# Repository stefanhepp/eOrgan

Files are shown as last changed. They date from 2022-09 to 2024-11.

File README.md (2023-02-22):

README
------

This project contains various parts of a midi-organ. The project consists of four
main parts:

- The Pedalboard: a 29 note midi foot pedal, mostly ARGO compliant. This odd number of notes
  was choosen because of size restrictions (I wanted it to fit under my e-piano).
- The organ console: contains stops, a lcd display, and all connectors and hardware to wire it to a PC.
  Up to three midi keyboards can be used as input devices, as well as the midi pedalboard.
- The organ desk: a framework for all the parts, contains speakers and some additional foot-stops.
  This is also designed to hold the PC. 
- The software: A controller software which allows access to some special features of the hardware
  and sets up the software synthesizer.

License
-------
Shield: [][cc-by-sa]

This work is licensed under a
[Creative Commons Attribution-ShareAlike 4.0 International License][cc-by-sa].

[][cc-by-sa]

[cc-by-sa]: http://creativecommons.org/licenses/by-sa/4.0/
[cc-by-sa-image]: https://licensebuttons.net/l/by-sa/4.0/88x31.png
[cc-by-sa-shield]: https://img.shields.io/badge/License-CC%20BY--SA%204.0-lightgrey.svg

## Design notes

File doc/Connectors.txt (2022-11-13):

Main Connector Groups
======================
o) Pedal
> Midi-Out   (Din5)
<  Power 5V+  (Buchse)

o) 10pin AVR ISP
 1: MOSI
 2: +5V
 3: (NC)
 4: GND
 5: RESET
 6: GND
 7: SCK
 8: GND
 9: MISO
10: GND

o) DIN-5 MIDI
 1: - 
 2: GND
 3: -
 4: 5V
 5: TX

o) 10pin Board Connector
 1: > UART TX
 2: > VCC 5V 
 3: < UART RX
 4: > VCC 12V 
 5: < Interrupt (Open Collector)
 6: > VCC 12V 
 7: > I2C SCL
 8: = GND
 9: = I2C SDA
10: = GND

o) 6pin MiniDIN Board Connector
 1: = I2C SDA
 2: < Interrupt (Open Collector
 3: = GND
 4: > VCC 5V
 5: > I2C SCL
 6: > VCC 12V

Archive
-------

O) Internal Connectors
- 8xPwr Conn.
  > VCC 5V                                    1
  = GND                                       2
  < PWR Main                                  2
  > Beleuchtung Spieltisch VCC+               2
  = Shortcut "Connected"                      1
- 36x Centronics Connector (34pol)
  < Beleuchtung On/off Signal to Relais       1
  > Midi In Pedal                             1
  > IO 3xPedal,8xFußsetzer                    11
  < Midi Out -> PC                            1
  < Volume                                    1
  < Boxen On/off                              1
  < Reverb                                    1
  > Line Kopfhörer                            2
  < PC Pwr                                    2
  < PC Reset                                  2
  > PC PWR LED                                2
  > PC HD LED                                 2
  = 2xUSB PC (Keyboard,Mouse,Setzer,..)       8

o) Stops Connector (34pol)
 1: VCC -> LED
 2: GND <- Taster
 3-34: n: Taster to GND, n+1: LED-

o) Stopboard Connector (14pol)
 1: = GND
 2: = GND
 3: > Bank Select/Register
 4: > Write(high)/Read(low)
 5: > A4
 6: > Read Enabled/LED Data (Write High)
 7: > A3
 8: < Interrupt/Data (Write low, Read High)
 9: > A2
10: > Koppel/Setzer Enable (low active)
11: > A1
12: > VCC 5V
13: > A0
14: > VCC 5V

o) Panel Connector (14Pol)
 1: = GND
 2: < VCC
 3: = GND
 4: < VCC
 5: < Reset
 6: > TxD
 7: > MOSI
 8: < RxD
 9: < MISO
10: ?
11: < SCK
12: ?
13: - ?VCC Lcd
14: -

o) LCD Connector (18pol, EA DIP204-4)
 1: = GND
 2: = D3
 3: = VCC 5V
 4: = D4 (D0)
 5: < Kontrast
 6: = D5 (D1)
 7: < RS/CS Befehl/Daten (Low for Chip Select in Serial Mode)
 8: = D6 (D2)
 9: < RW H=Read, L=Write (Data input in Serial Mode)
10: = D7 (D3), MSB
11: < SCLK Enable (fallende Flanke) (Clock in Serial Mode)
12: -
13: = D0, LSB (Data Out in Serial Mode)
14: < RESET (Low Active, interner Pullup 10K)
15: = D1
16: = A Led Beleuchtung +
17: = D2
18: = C Led Beleuchtung -  

o) LCD Keys Connector (12pol Pinheader)
 1: = GND
 2: = GND
 3: > Kontrast Poti In
 4: < Kontrast Poti Out
 5: < T1
 6: < T2
 7: < T3
 8: < T4
 9: < T5
10: < T6
11: < T7
12: < T8

o) Impuls Connector (Drehimpulsknopf, 5Pol)
 1: < A
 2: < C
 3: < B
 4: < P1
 5: > P2

o) Control Connector (20pol)
 1: > VCC
 2: = GND
 4: < Pwr Main Led
 5: < Pwr Light Led
 6: > Pwr Main
 7: < Pwr Light Sw
 8: < Pwr Main
 9: < Hdd Led
10: > Pwr Sw
11: > Hdd Led
12: < Pwr Sw
13: > Reset Sw
14: < Boxen Sw
15: < Reset Sw
16: < Boxen Led
17: > Pwr Led
18: < Pwr Led
19: < Reverb
20: < Volume

o) Koppel Register

o) Data Connector

-- Onboard Connector --
o) Register (2x)
> 1x Register
< 2x Drawknob

o) Controller
= 2x Register
< 1x Koppel
< 3x Midi-In
> 1x Midi-Out
= 1x Panel
= 1x Control
< 1x Koppel
= 1x Data

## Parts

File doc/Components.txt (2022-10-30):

o) Pedal
1x  AT90S2313P/AtMega48
1x  4069
1x  4556
1x  DIL Socket 20pin
1x  DIL Socket 16pin
1x  DIL Socket 14pin
1x  Quarz 4Mhz
1x  Pin Header male 2x7 pin
1x  Pin Header male 2x5 pin
1x  Pin Header male 2x3 pin
1x  Pin Header female 2x7 pin
2x  220R
10x 4k7
1x  Taster
1x  DIN 180° 5pin female
1x  Pwr out
1x  7805
1x  1N4004
1x  100nF
1x  10uF
32x Reed switch
32x 1N4148

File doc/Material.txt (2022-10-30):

---- Pedal ----
o) Tasten: 29 Keys, Kiefer/Esche, 2.5cm 
  29x	82 x 3x2.5cm hell
  17x	65 x 3x2.5cm hell
  12x	18 x 6x2.5cm dunkel/hell+lack (= 24x 18x3x2.5cm)

o) Rahmen: Kiefer 2cm
  4x	48 x 10x2cm
  2x	85 x 10x2cm
  4x	65 x 12x2cm
  1x	1m x 12x2cm (2xToeboard)
  2x	12 x 12x2cm

o) Struktur: Fichte,Kiefer
  2x	90 x 10x2cm
  2x	10 x 10x2cm
  2x	52 x 12x2cm
  2x	46 x 3x2.5cm
  4x	 8 x 3x2.5cm
  2x	62 x 2x2.5cm
  4x	62 x 0.5x3cm
  2x	46 x 1cm halbrund
  31x	10 x 1cm rund
  29x	2.5 x 0.6cm rund

o) Sonstiges
  4x	12 x 10x0.3cm Blech
  2x	46 x 2cm Filz grün/blau
  58x	10 x 2cm Filz grün/blau
  29x	2 x 2cm Filz grün/blau
  2x	5cm Scharnier
  29x	4x0.2cm Stahlnagel
  29x	7.5 x M8 Feder

------------------
  3x	2m x 10x2cm Kiefer
	 1x 4x48
	 1x 2x82
	 1x 2x90+2x10 + 2x 58x2x2.5
  2x	2m x 12x2cm Kiefer
	 1x 3x65
	 1x 1x65+2x55+2x12
  1x	1m x 12x2cm Kiefer (2x Toeboard)
  6x	2m x 3x2.5cm Esche
	 5x 3x65
	 1x 2x65+1x46
  14x	2m x 3x2.5cm Kiefer
	12x 2x82+2x18
	 2x 2x82+4x8
	 1x 1x46+1x82
  1x	2m x  3x0.5cm Kiefer (3x62)
  1x	1m x  3x0.5cm Kiefer (1x62)
  4x	1m x 1cm rund Buche
  2x	1m x 0.6cm rund Buche
  1x	1m x 1cm halbrund
  1x	50cm x 100x3mm Blech
  1x	40cm x 40cm Filz grün/blau

---- Bank -----
  1x	120 x 30x3cm
  2x	65  x 30x3cm
  3x	110 x 10x3cm

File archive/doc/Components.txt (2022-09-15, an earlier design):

o) Pedal
1x  AT90S2313P/AtMega48
1x  4069
1x  4556
1x  DIL Socket 20pin
1x  DIL Socket 16pin
1x  DIL Socket 14pin
1x  Quarz 4Mhz
1x  Pin Header male 2x7 pin
1x  Pin Header male 2x5 pin
1x  Pin Header male 2x3 pin
1x  Pin Header female 2x7 pin
2x  220R
10x 4k7
1x  Taster
1x  DIN 180° 5pin female
1x  Pwr out
1x  7805
1x  1N4004
1x  100nF
1x  10uF
32x Reed switch
32x 1N4148

o) LcdPanel
1x  AtMega48
1x  DIL Socket 28pin
1x  Quarz 16Mhz
2x  22pF
1x  Pin Header male 2x5 pin
1x  Pin header male 1x5 pin
1x  Pin header male 2x6 pin
1x  Pin header male 2x7 pin
2x  Pin header female 1x10pin, 2mm
1x  Pin header female 1x5 pin
3x  33nF
4x  10k
1x  BC557
1x  680
1x  27
8x  Button
1x  Impulsgeber

o) Register (2x)
4x  4099
2x  4067
1x  4572
1x  4023
1x  4556
2x  DIL Socket 24pin
6x  DIL Socket 16pin
1x  DIL Socket 14pin
2x  Pin header male 2x17 pin
1x  Pin header male 2x7 pin
1x  Pin header male 2x1 pin
2x  Pin header female 2x17 pin
32x 220R
1x  10k
29x Led yellow
2x  Led green
1x  Led red

o) Control Panel 
1x  Keylock
1x  Switch + LED green (pwr)
2x  Taster + LED green/red
2x  Switch
2x  Poti
1x  Pin header female 2x7 pin

o) Koppler
12x Taster + LED (square)
6x  Taster + LED (round)
6x  Wippschalter/Taster 2pos + LED
6x  Wippschalter 3pos
2x  Taster
1x  Poti

o) Audio panel
2x  Klinke 3.5mm
2x  USB Port
2x  Poti (Volume)

o) Controller
3x  AtMega16
3x  DIL socket 40pin
1x  7805
3x  Quarz 16Mhz
5x  DIN 180° 5pin female
4x  6N125
3x  Pin header male 2x7 pin
1x  USB header
2x  Zehner 3.7V
2x  68R
1x  1k5
2x  22pF
1x  100nF
1x  10uF

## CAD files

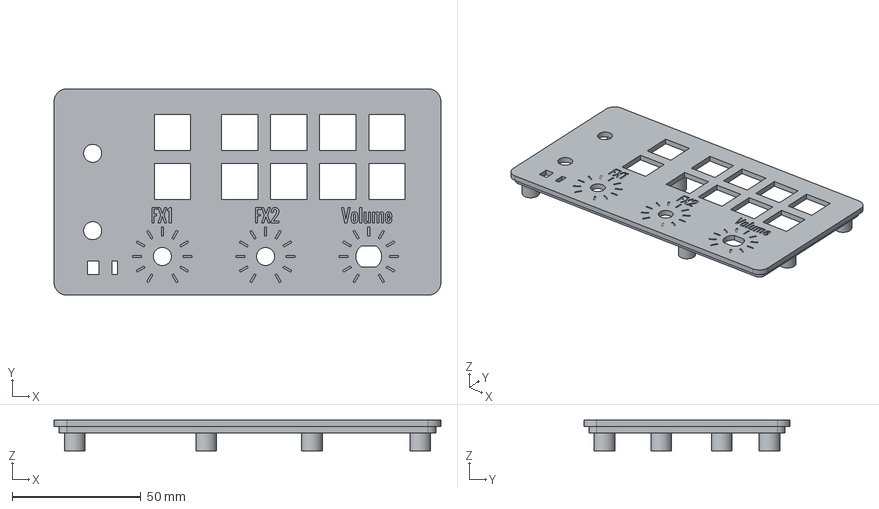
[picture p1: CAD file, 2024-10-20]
design/Panel Inserts-MainControl.step
150.0 x 80.0 x 12.0 mm

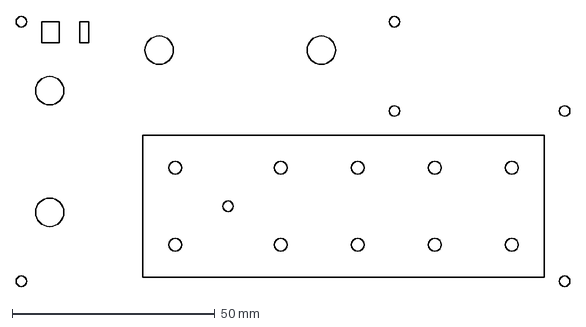
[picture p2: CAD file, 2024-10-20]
design/Panel Inserts-MainControlPCB Drillholes.dxf
136.6 x 66.6 mm

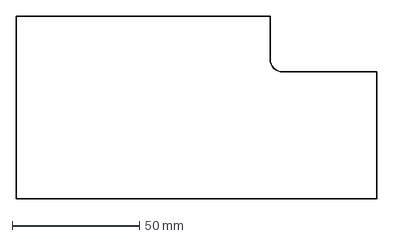
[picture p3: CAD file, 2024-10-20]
design/Panel Inserts-MainControlPCB Edgecut.dxf
142.0 x 72.0 mm

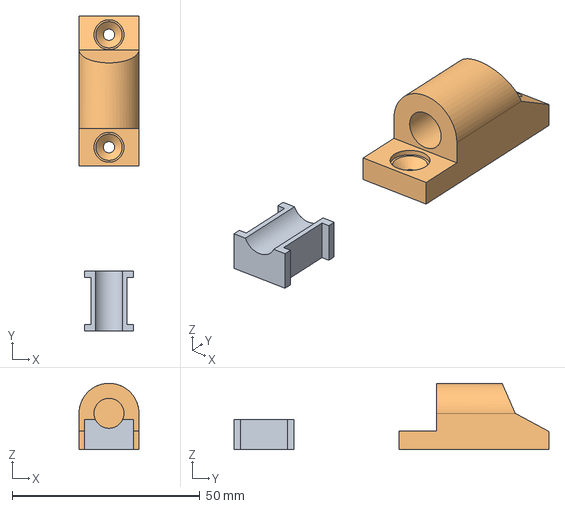
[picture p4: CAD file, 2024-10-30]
design/Musicstand Holder.FCStd
16.0 x 84.0 x 17.7 mm
Spacer
Top

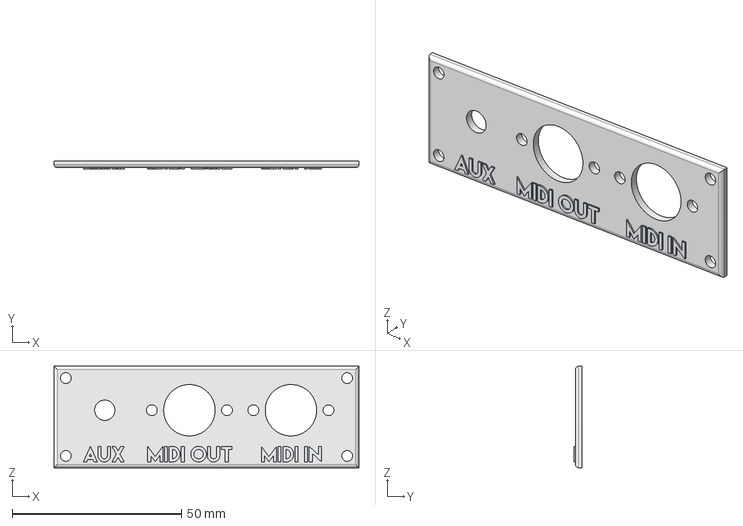
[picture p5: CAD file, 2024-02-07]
design/parts/Audio Frontpanel.FCStd
90.1 x 2.40 x 30.0 mm

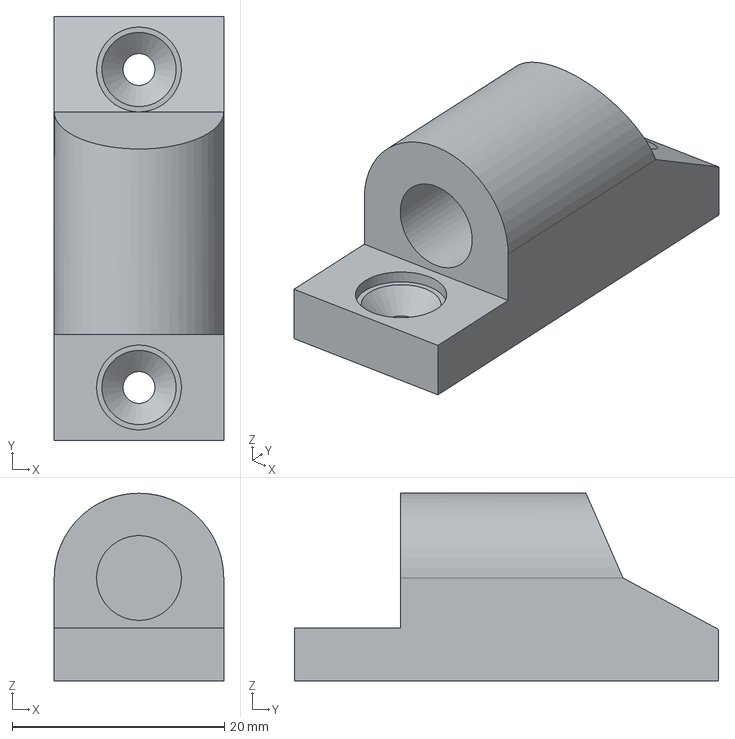
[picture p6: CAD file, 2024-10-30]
design/Musicstand Holder-Top.step
16.0 x 40.0 x 17.7 mm

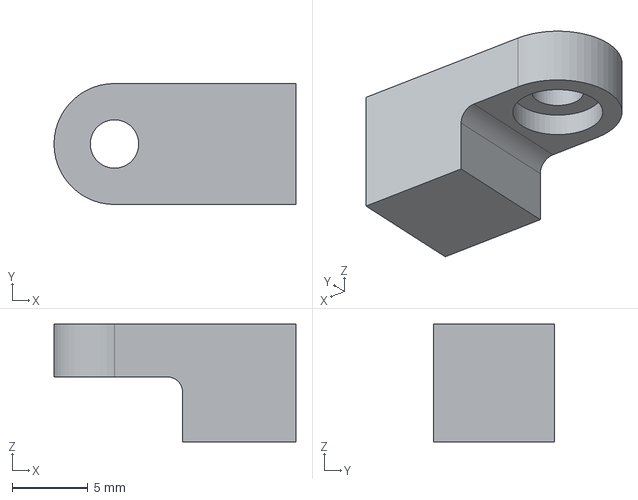
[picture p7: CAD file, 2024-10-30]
design/Display Clamp.step
16.0 x 8.00 x 7.80 mm

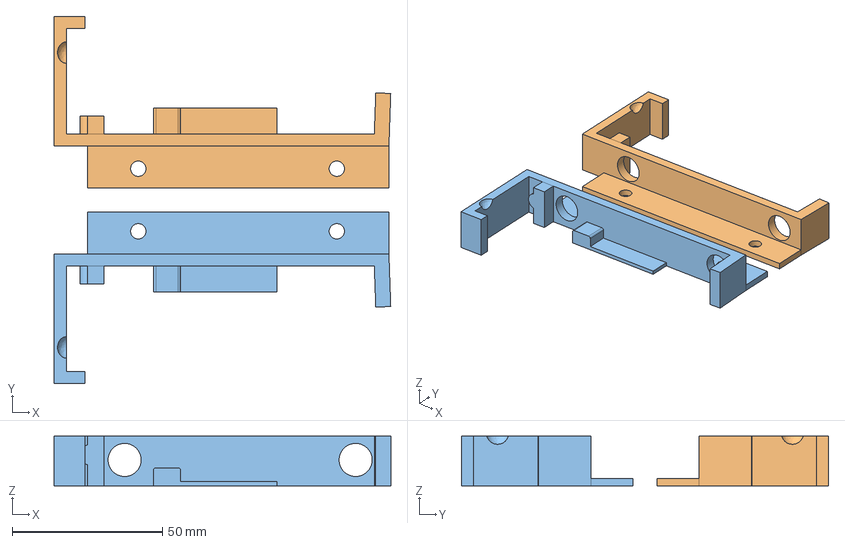
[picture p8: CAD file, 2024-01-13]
design/parts/BoutiqueBracketWRetentionHook.FCStd
111.9 x 122.0 x 16.5 mm
RBracket
CloneBody
LBracket

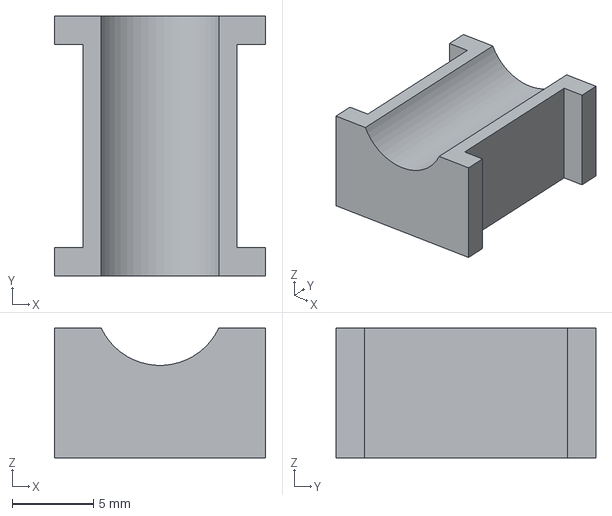
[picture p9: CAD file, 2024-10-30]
design/Musicstand Holder-Spacer.step
13.0 x 16.0 x 8.00 mm

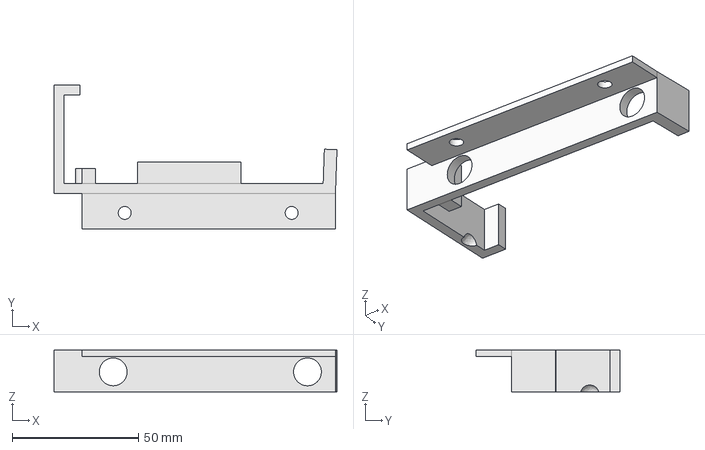
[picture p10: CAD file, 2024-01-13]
design/parts/BoutiqueBracketWRetentionHook-LBracket.step
111.9 x 57.0 x 16.5 mm

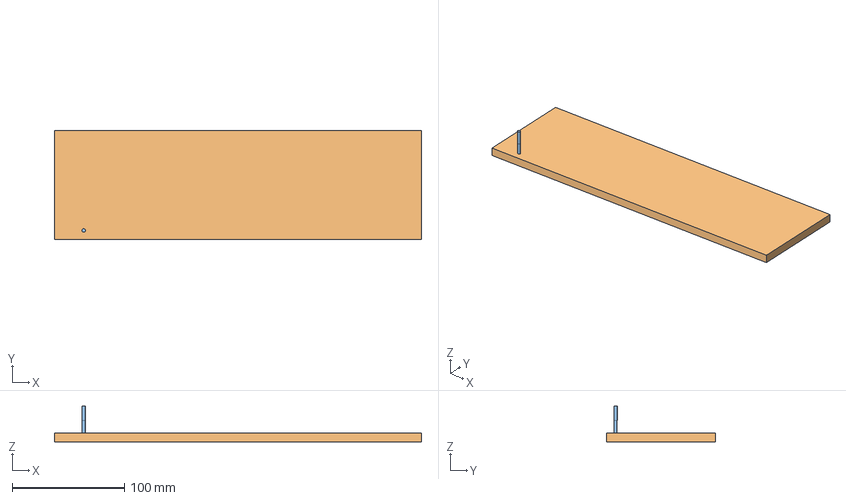
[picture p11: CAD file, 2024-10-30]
design/Panel Cutout Right.FCStd
327.0 x 97.0 x 32.0 mm
Model-Body
Stock
3mm 2-flute Endmill

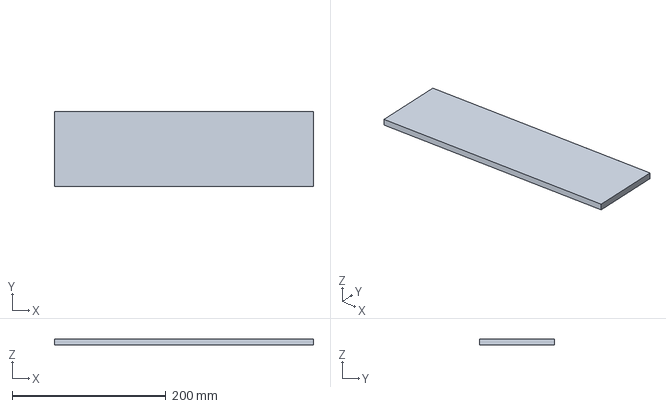
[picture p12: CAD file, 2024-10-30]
design/Panel Cutout Display.FCStd
337.0 x 97.0 x 8.00 mm

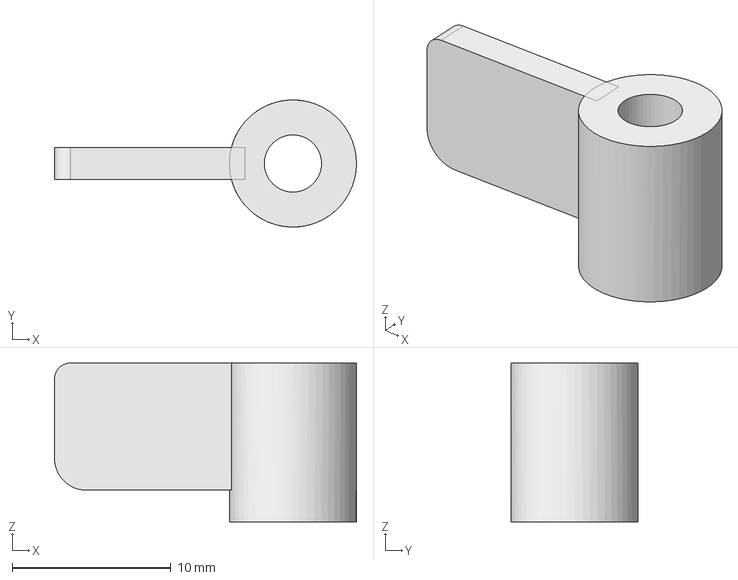
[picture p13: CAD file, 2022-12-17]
design/parts/Hatchlock.FCStd
19.0 x 8.00 x 10.0 mm

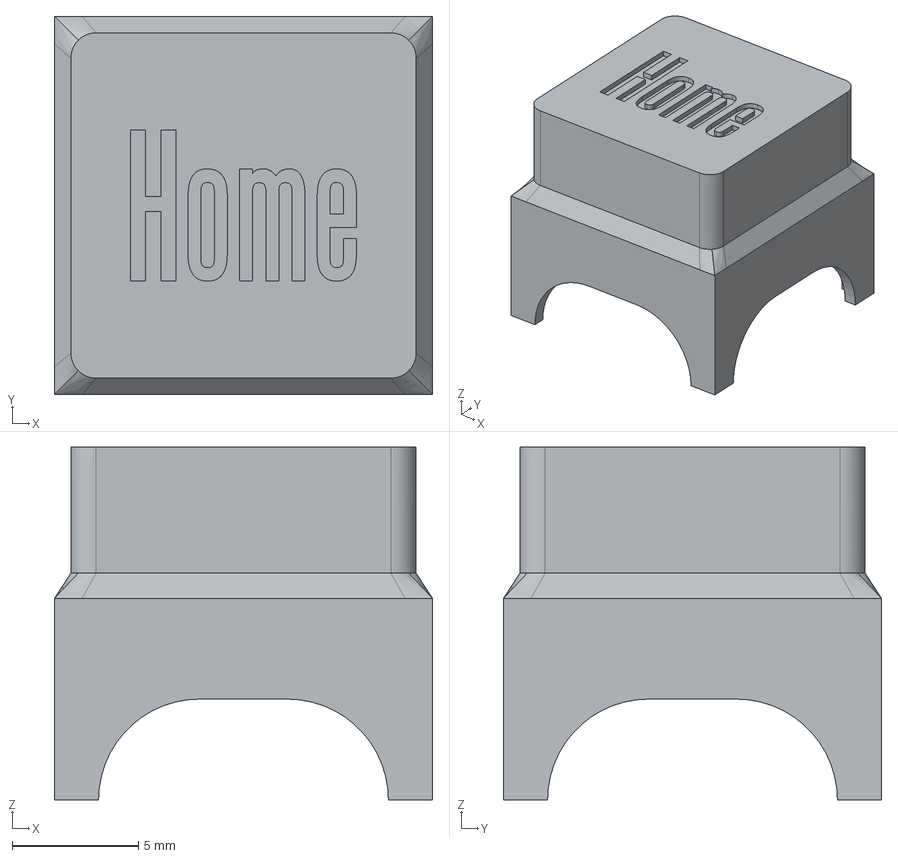
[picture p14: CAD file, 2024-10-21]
design/Panel Keycaps-Keycap Home.step
15.0 x 15.0 x 14.0 mm

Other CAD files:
design/parts/Audio Frontpanel-Panel.step
design/parts/BoutiqueBracketWRetentionHook-RBracket.step
design/parts/Powerswitch Case.FCStd
design/Panel Keycaps-Keycap OK.step
design/Display Clamp.FCStd
design/Lock Mount-Body Left.step
design/Lock Mount-Body Right.step
design/Lock Mount.FCStd
design/Music Rack.FCStd
design/Organ-v2.blend
design/Organ.blend
design/PCB Holder Technics-Holder 110x53.step
design/PCB Holder-150x100.step
design/PCB Holder-Base.step
design/PCB Holder-LCD.step
design/PCB Holder-Pedal.step
design/PCB Holder-Technics.step
design/PCB Holder.FCStd
design/Panel Inserts-Buttons.step
design/Panel Inserts.FCStd
design/Panel Keycaps-Keycap Audio.step
design/Panel Keycaps-Keycap Back.step
design/Panel Keycaps-Keycap Coupler.step
design/Panel Keycaps-Keycap Presets.step
design/Panel Keycaps-Keycap Router.step
design/Panel Keycaps-Keycap Seq.step
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

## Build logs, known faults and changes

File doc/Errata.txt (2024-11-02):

Changes
-------

o) PedalEncoder
- ISP header SCK,MISO,MOSI pins fixed
  - Workaround: rewire jumper wires

o) MIDIController
- Fixed mirrored MIDI breakout board connector
  - Workaround: reverse IDC16 board
- Fixed swapped I2S data signals
  - Workaround: cross-wire I2S data lines

o) ToeStudController
- Fixed PS2 pin order
  - Workaround: cross-wire cables MIDIController-IO Board <> ToeStudEncoder and ToeStudEncoder <> Pedal

o) PanelMain
- Fixed 5V Pwr LED using main 5V instead of MainPanel 5V
  - Workaround: none
- Missing pullups on button columns
  - Workaround: Pullup adapter board

o) Panel-Breakout
- Raspberry PI I2C-0 requires external pullups, added
  - Workaround: Added Panel-Breakup-I2CPullup board to add pullups

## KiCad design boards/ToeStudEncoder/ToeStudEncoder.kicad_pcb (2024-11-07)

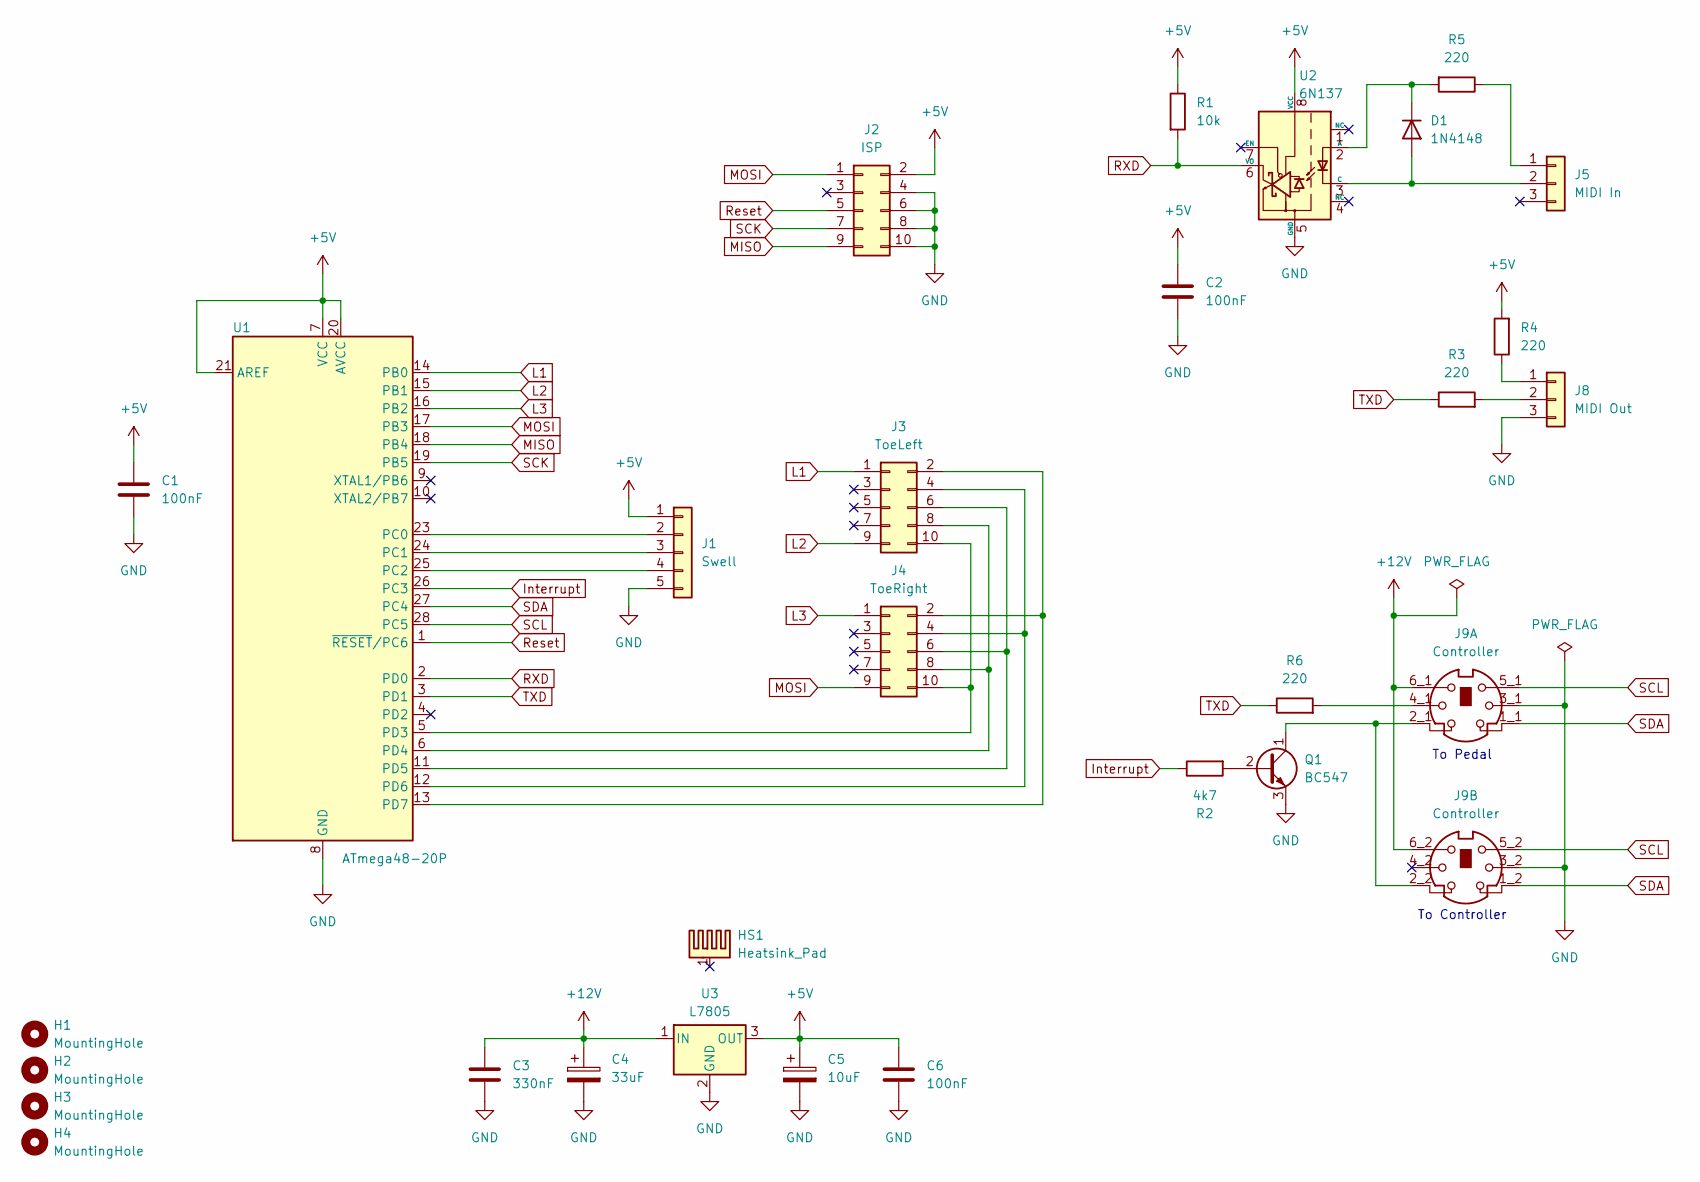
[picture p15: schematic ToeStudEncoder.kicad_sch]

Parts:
C1, C2: 100nF; C_Disc_D7.5mm_W2.5mm_P5.00mm
C3: 330nF; C_Disc_D4.3mm_W1.9mm_P5.00mm
C4: 33uF; CP_Radial_D7.5mm_P2.50mm
C5: 10uF; CP_Radial_D6.3mm_P2.50mm
C6: 100nF; C_Disc_D4.3mm_W1.9mm_P5.00mm
D1: 1N4148; D_DO-35_SOD27_P7.62mm_Horizontal
H1, H2, H3, H4: MountingHole; MountingHole_3mm
HS1: Heatsink_Pad; Heatsink_Aavid_TO-220_H12.7mm
J1: Swell; JST_XH_B5B-XH-A_1x05_P2.50mm_Vertical
J2: ISP; IDC-Header_2x05_P2.54mm_Vertical
J3: ToeLeft; IDC-Header_2x05_P2.54mm_Vertical
J4: ToeRight; IDC-Header_2x05_P2.54mm_Vertical
J5: MIDI In; PinHeader_1x03_P2.54mm_Vertical
J8: MIDI Out; PinHeader_1x03_P2.54mm_Vertical
J9: Controller; SWITCHCRAFT_DMD6FRA111
Q1: BC547; TO-92_Inline_Wide
R1: 10k; R_Axial_DIN0207_L6.3mm_D2.5mm_P2.54mm_Vertical
R2: 4k7; R_Axial_DIN0207_L6.3mm_D2.5mm_P2.54mm_Vertical
R3, R4, R6: 220; R_Axial_DIN0207_L6.3mm_D2.5mm_P10.16mm_Horizontal
R5: 220; R_Axial_DIN0207_L6.3mm_D2.5mm_P2.54mm_Vertical
U1: ATmega48-20P; DIP-28_W7.62mm
U2: 6N137; DIP-8_W7.62mm
U3: L7805; TO-220-3_Vertical

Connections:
+5V: C1.1, C2.1, C5.1, C6.1, J1.1, J2.2, R1.1, R4.2, U1.7 (VCC), U1.20 (AVCC), U1.21 (AREF), U2.8 (VCC), U3.3 (OUT)
+12V: C3.1, C4.1, J9.6_1, J9.6_2, U3.1 (IN)
GND: C1.2, C2.2, C3.2, C4.2, C5.2, C6.2, J1.5, J2.4, J2.6, J2.8, J2.10, J8.3, J9.3_1, J9.3_2, Q1.3 (E), U1.8 (GND), U1.22 (GND), U2.5 (GND), U3.2 (GND)
Interrupt: R2.1, U1.26 (PC3)
L1: J3.1, U1.14 (PB0)
L2: J3.9, U1.15 (PB1)
L3: J4.1, U1.16 (PB2)
MISO: J2.9, U1.18 (PB4)
MOSI: J2.1, J4.9, U1.17 (PB3)
unnamed: D1.2 (A), J5.2, U2.3 (C)
unnamed: D1.1 (K), R5.2, U2.2 (A)
unnamed: J1.2, U1.23 (PC0)
unnamed: J1.3, U1.24 (PC1)
unnamed: J1.4, U1.25 (PC2)
unnamed: J3.2, J4.2, U1.13 (PD7)
unnamed: J3.4, J4.4, U1.12 (PD6)
unnamed: J3.6, J4.6, U1.11 (PD5)
unnamed: J3.8, J4.8, U1.6 (PD4)
unnamed: J3.10, J4.10, U1.5 (PD3)
unnamed: J5.1, R5.1
unnamed: J8.1, R4.1
unnamed: J8.2, R3.2
unnamed: J9.4_1, R6.2
unnamed: Q1.2 (B), R2.2
unnamed: J9.2_1, J9.2_2, Q1.1 (C)
RXD: R1.2, U1.2 (PD0), U2.6 (VO)
Reset: J2.5, U1.1 (~RESET/PC6)
SCK: J2.7, U1.19 (PB5)
SCL: J9.5_1, J9.5_2, U1.28 (PC5)
SDA: J9.1_1, J9.1_2, U1.27 (PC4)
TXD: R3.1, R6.1, U1.3 (PD1)

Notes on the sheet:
To Controller
To Pedal

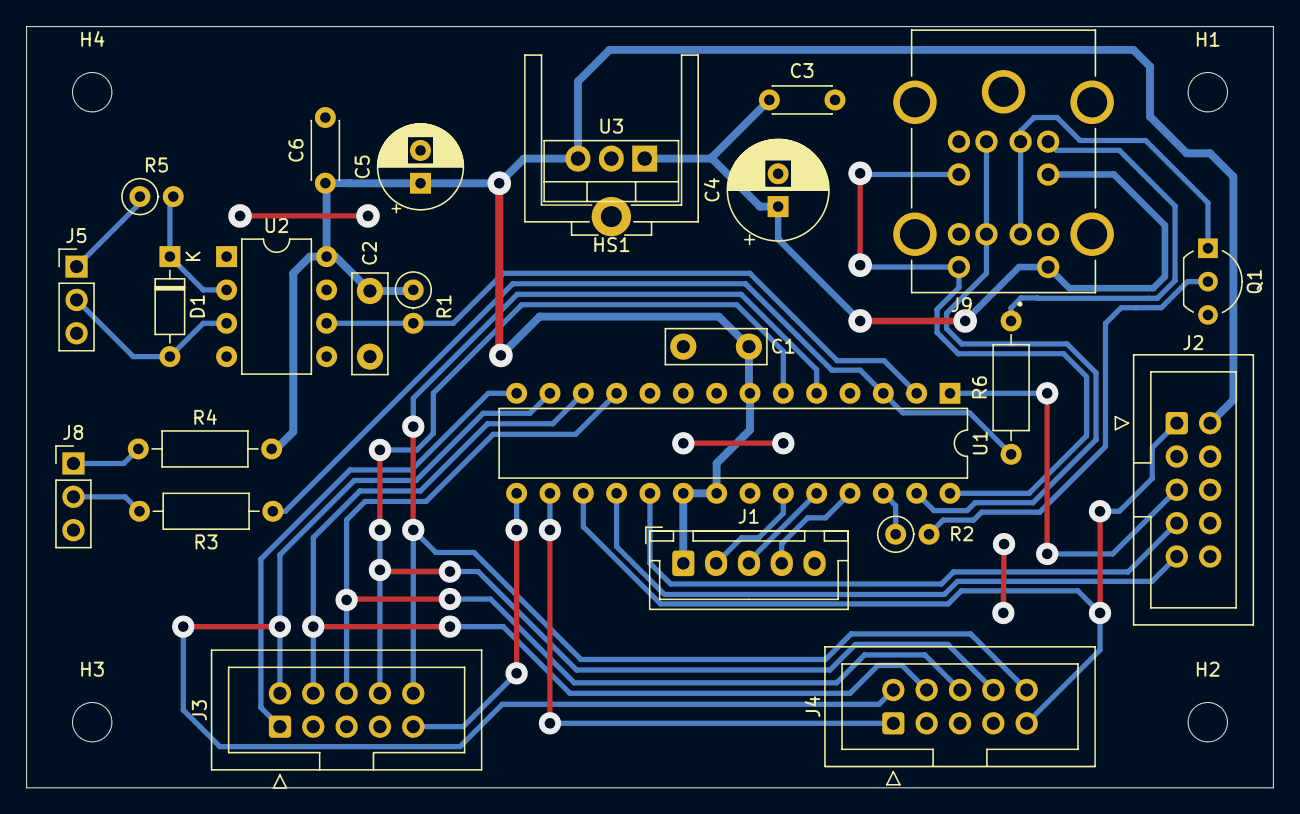
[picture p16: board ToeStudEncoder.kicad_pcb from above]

Board: 2 copper layers, 95.0 x 58.0 mm, 29 parts (0 on the bottom side), 31 nets.

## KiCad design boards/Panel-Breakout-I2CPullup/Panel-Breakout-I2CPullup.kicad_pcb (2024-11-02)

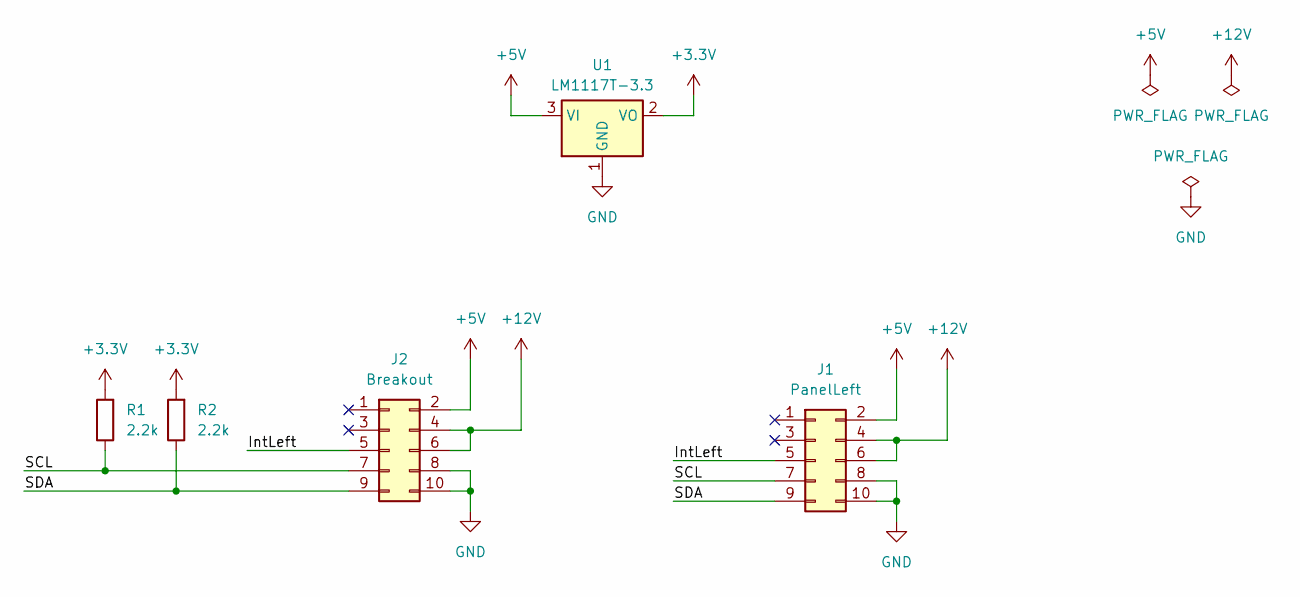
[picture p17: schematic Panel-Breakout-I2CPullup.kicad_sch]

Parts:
J1: PanelLeft; IDC-Header_2x05_P2.54mm_Vertical
J2: Breakout; IDC-Header_2x05_P2.54mm_Vertical
R1, R2: 2.2k; R_Axial_DIN0207_L6.3mm_D2.5mm_P10.16mm_Horizontal
U1: LM1117T-3.3; TO-220-3_Vertical

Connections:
+3.3V: R1.2, R2.2, U1.2 (VO)
+5V: J1.2, J2.2, U1.3 (VI)
+12V: J1.4, J1.6, J2.4, J2.6
/IntLeft: J1.5, J2.5
/SCL: J1.7, J2.7, R1.1
/SDA: J1.9, J2.9, R2.1
GND: J1.8, J1.10, J2.8, J2.10, U1.1 (GND)

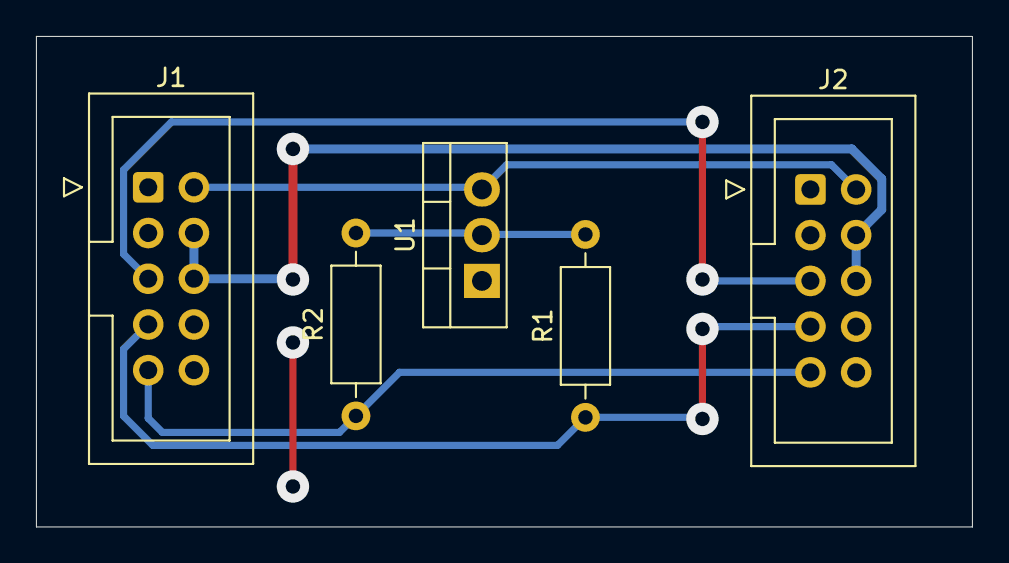
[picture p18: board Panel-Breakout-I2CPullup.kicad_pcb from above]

Board: 2 copper layers, 52.0 x 27.2 mm, 5 parts (0 on the bottom side), 7 nets.

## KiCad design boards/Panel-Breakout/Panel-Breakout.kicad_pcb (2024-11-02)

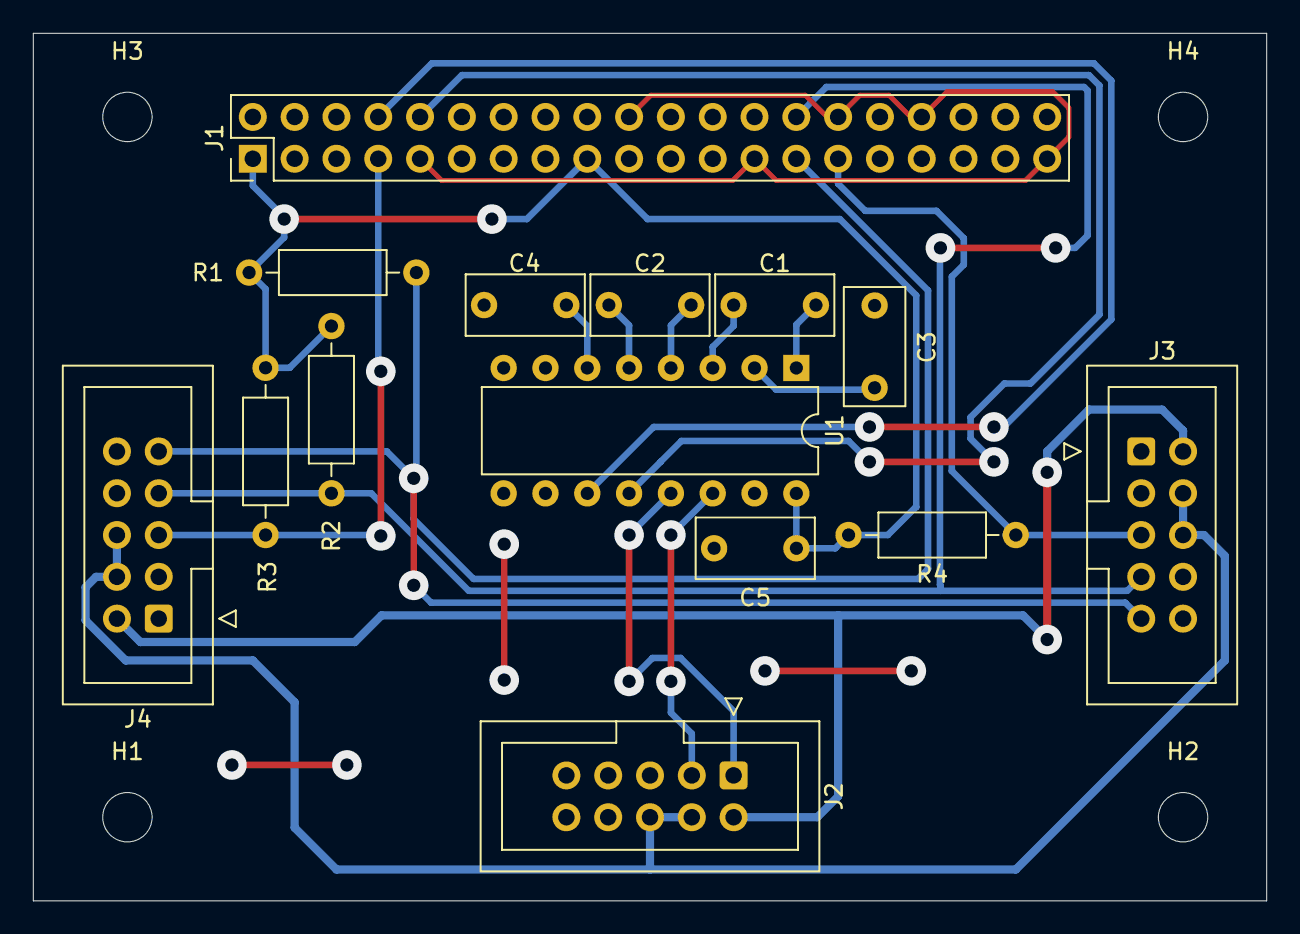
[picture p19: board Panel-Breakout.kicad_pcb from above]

Board: 2 copper layers, 74.9 x 52.7 mm, 18 parts (0 on the bottom side), 18 nets.

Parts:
C1, C2, C3, C4, C5: 0.47uF; C_Rect_L7.0mm_W3.5mm_P5.00mm
H1, H2, H3, H4: MountingHole; MountingHole_3mm
J1: Raspberry_Pi_2_3; PinHeader_2x20_P2.54mm_Vertical
J2: BoardCon; IDC-Header_2x05_P2.54mm_Vertical
J3: PanelLeft; IDC-Header_2x05_P2.54mm_Vertical
J4: PanelRight; IDC-Header_2x05_P2.54mm_Vertical
R1, R2: 2.2k; R_Axial_DIN0207_L6.3mm_D2.5mm_P10.16mm_Horizontal
R3, R4: 10k; R_Axial_DIN0207_L6.3mm_D2.5mm_P10.16mm_Horizontal
U1: ICL3232; DIP-16_W7.62mm

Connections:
+3.3V: C5.1, J1.1 (3V3), J1.17 (3V3), R1.2, R2.2, R3.2, R4.2, U1.16 (VCC)
+5V: J2.2, J3.2, J4.2
+12V: J2.4, J2.6, J3.4, J3.6, J4.4, J4.6
/IntLeft: J1.29 (GCLK1/GPIO5), J3.5, R4.1
/IntRight: J1.7 (GCLK0/GPIO4), J4.5, R3.1
/RPI_RXD: J1.10 (GPIO15/RXD), U1.12 (R1OUT)
/RPI_TXD: J1.8 (GPIO14/TXD), U1.11 (T1IN)
/RS232_RXD: J2.1, U1.13 (R1IN)
/RS232_TXD: J2.3, U1.14 (T1OUT)
/SCL: J1.28 (ID_SC/GPIO1), J3.7, J4.7, R2.1
/SDA: J1.27 (ID_SD/GPIO0), J3.9, J4.9, R1.1
GND: C3.2, C4.2, C5.2, J1.6 (GND), J1.9 (GND), J1.14 (GND), J1.20 (GND), J1.25 (GND), J1.30 (GND), J1.34 (GND), J1.39 (GND), J2.8, J2.10, J3.8, J3.10, J4.8, J4.10, U1.8 (R2IN), U1.10 (T2IN), U1.15 (GND)
unnamed: C1.1, U1.1 (C1+)
unnamed: C1.2, U1.3 (C1-)
unnamed: C2.1, U1.4 (C2+)
unnamed: C2.2, U1.5 (C2-)
unnamed: C3.1, U1.2 (VS+)
unnamed: C4.1, U1.6 (VS-)

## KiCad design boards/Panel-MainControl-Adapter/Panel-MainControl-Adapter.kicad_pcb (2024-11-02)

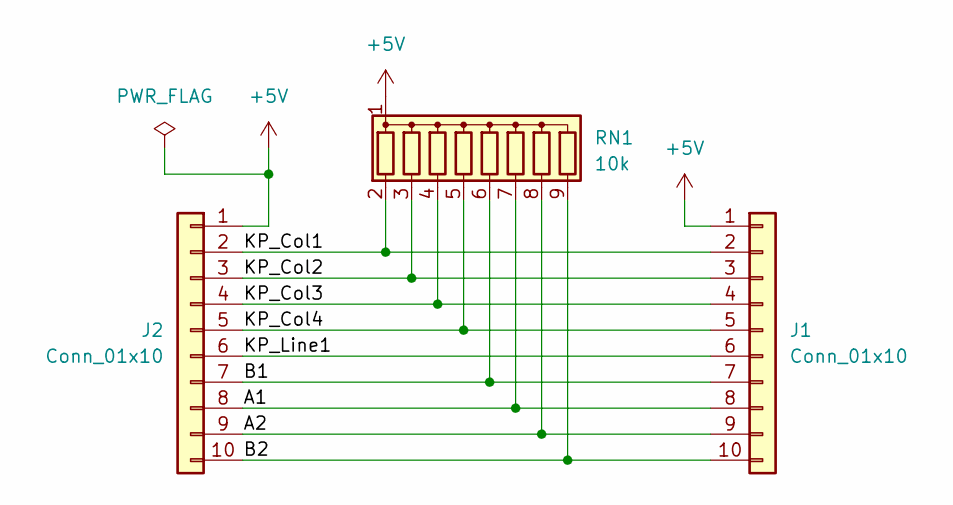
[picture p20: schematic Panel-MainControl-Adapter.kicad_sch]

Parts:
J1, J2: Conn_01x10; PinHeader_1x10_P2.00mm_Vertical
RN1: 10k; R_Array_SIP9

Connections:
+5V: J1.1, J2.1, RN1.1 (common)
/A1: J1.8, J2.8, RN1.7 (R6)
/A2: J1.9, J2.9, RN1.8 (R7)
/B1: J1.7, J2.7, RN1.6 (R5)
/B2: J1.10, J2.10, RN1.9 (R8)
/KP_Col1: J1.2, J2.2, RN1.2 (R1)
/KP_Col2: J1.3, J2.3, RN1.3 (R2)
/KP_Col3: J1.4, J2.4, RN1.4 (R3)
/KP_Col4: J1.5, J2.5, RN1.5 (R4)
/KP_Line1: J1.6, J2.6

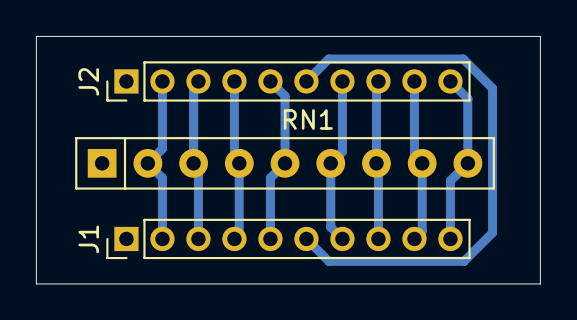
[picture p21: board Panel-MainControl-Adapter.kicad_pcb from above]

Board: 2 copper layers, 28.0 x 13.8 mm, 3 parts (0 on the bottom side), 10 nets.

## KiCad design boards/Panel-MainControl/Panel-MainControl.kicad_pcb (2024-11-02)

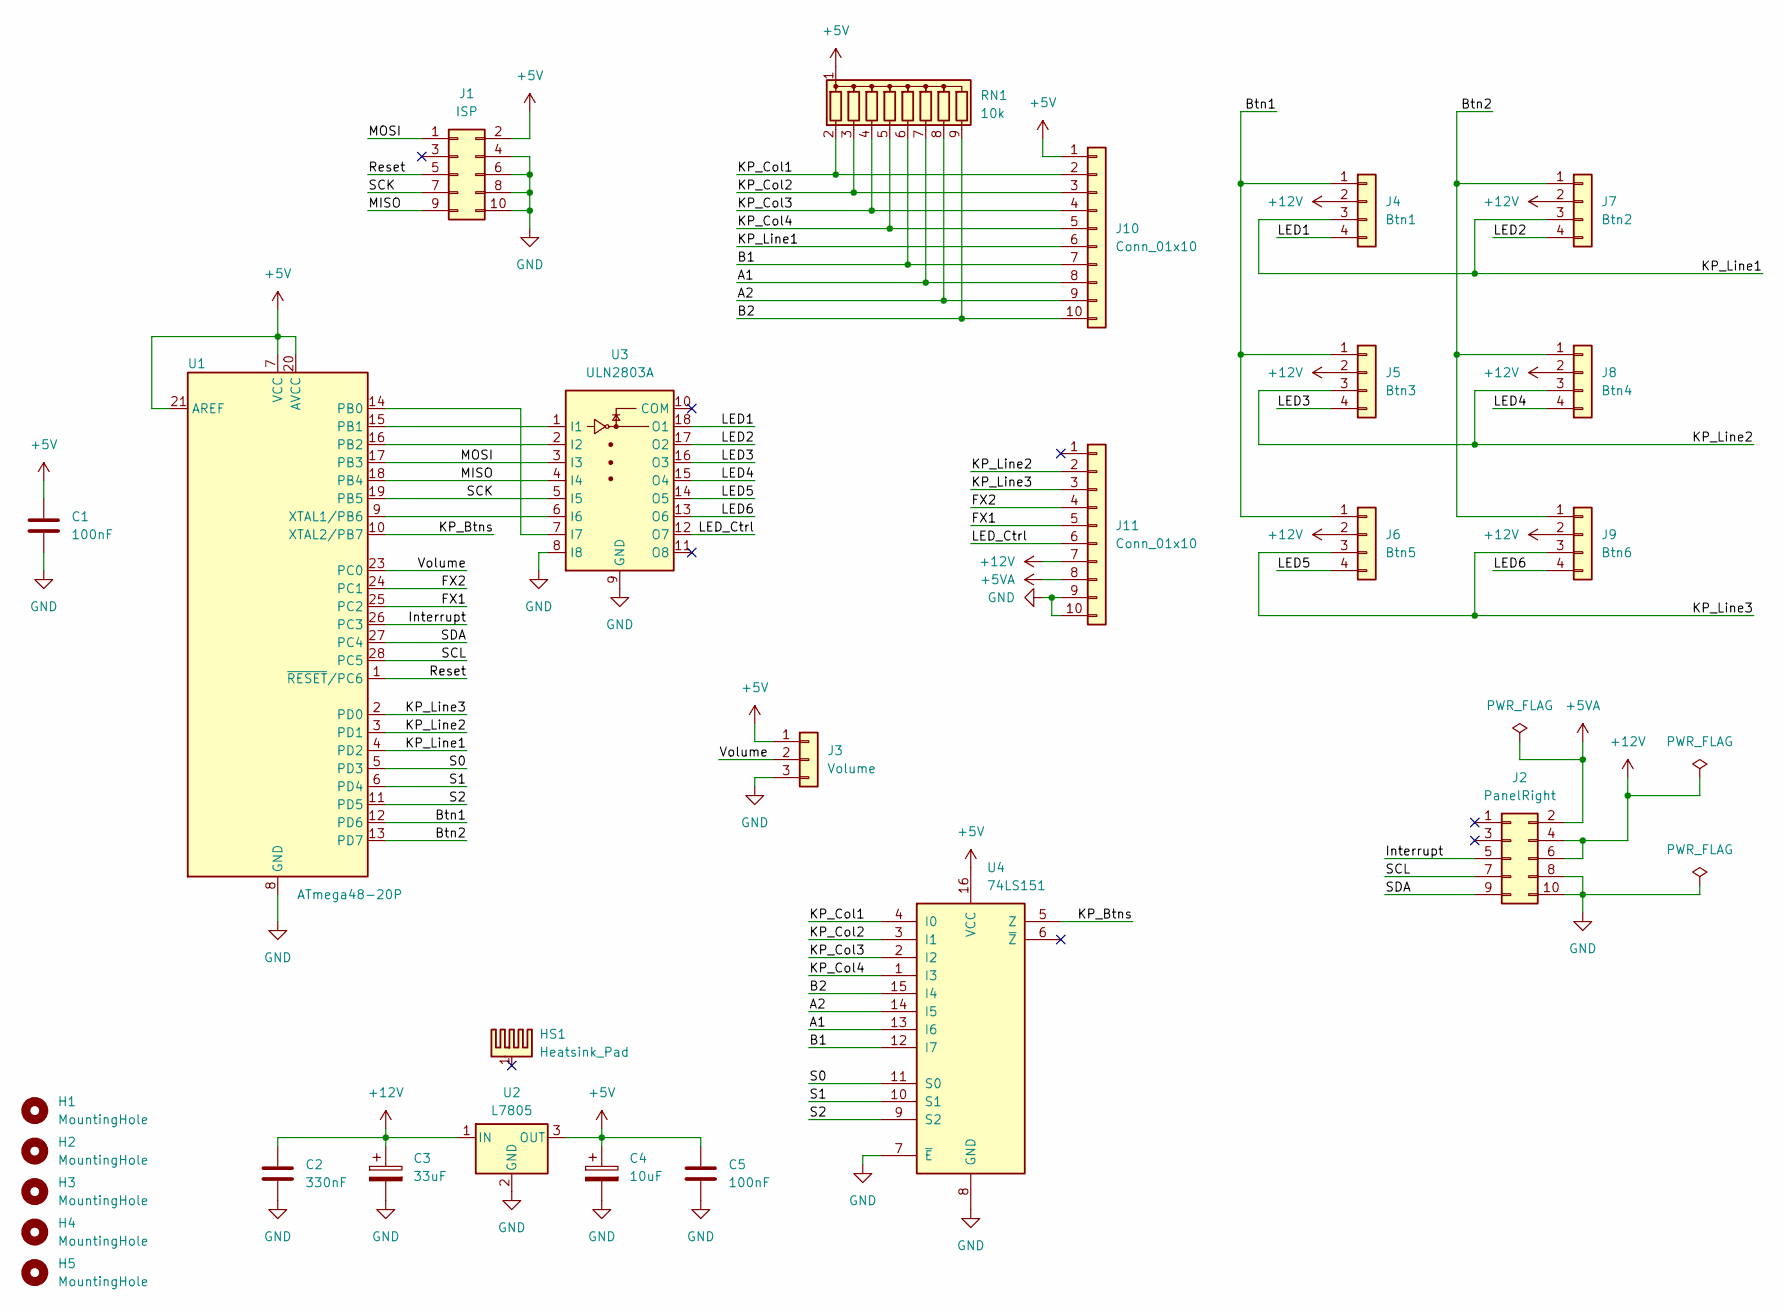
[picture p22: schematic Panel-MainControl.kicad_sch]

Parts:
C1, C5: 100nF; C_Disc_D4.3mm_W1.9mm_P5.00mm
C2: 330nF; C_Disc_D4.3mm_W1.9mm_P5.00mm
C3: 33uF; CP_Radial_D7.5mm_P2.50mm
C4: 10uF; CP_Radial_D6.3mm_P2.50mm
H1, H2, H3, H4, H5: MountingHole; MountingHole_2.7mm_M2.5
HS1: Heatsink_Pad; Heatsink_Aavid_TO-220_H12.7mm
J1: ISP; IDC-Header_2x05_P2.54mm_Vertical
J2: PanelRight; IDC-Header_2x05_P2.54mm_Vertical
J3: Volume; PinHeader_1x03_P2.54mm_Vertical
J4: Btn1; JST_XH_B4B-XH-A_1x04_P2.50mm_Vertical
J5: Btn3; JST_XH_B4B-XH-A_1x04_P2.50mm_Vertical
J6: Btn5; JST_XH_B4B-XH-A_1x04_P2.50mm_Vertical
J7: Btn2; JST_XH_B4B-XH-A_1x04_P2.50mm_Vertical
J8: Btn4; JST_XH_B4B-XH-A_1x04_P2.50mm_Vertical
J9: Btn6; JST_XH_B4B-XH-A_1x04_P2.50mm_Vertical
J10, J11: Conn_01x10; PinHeader_1x10_P2.00mm_Vertical
RN1: 10k; R_Array_SIP9
U1: ATmega48-20P; DIP-28_W7.62mm_Socket
U2: L7805; TO-220-3_Vertical
U3: ULN2803A; DIP-18_W7.62mm
U4: 74LS151; DIP-16_W7.62mm

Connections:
+5V: C1.1, C4.1, C5.1, J1.2, J3.1, J10.1, RN1.1 (common), U1.7 (VCC), U1.20 (AVCC), U1.21 (AREF), U2.3 (OUT), U4.16 (VCC)
+5VA: J2.2, J11.8
+12V: C2.1, C3.1, J2.4, J2.6, J4.2, J5.2, J6.2, J7.2, J8.2, J9.2, J11.7, U2.1 (IN)
/A1: J10.8, RN1.7 (R6), U4.13 (I6)
/A2: J10.9, RN1.8 (R7), U4.14 (I5)
/B1: J10.7, RN1.6 (R5), U4.12 (I7)
/B2: J10.10, RN1.9 (R8), U4.15 (I4)
/Btn1: J4.1, J5.1, J6.1, U1.12 (PD6)
/Btn2: J7.1, J8.1, J9.1, U1.13 (PD7)
/FX1: J11.5, U1.25 (PC2)
/FX2: J11.4, U1.24 (PC1)
/Interrupt: J2.5, U1.26 (PC3)
/KP_Btns: U1.10 (XTAL2/PB7), U4.5 (Z)
/KP_Col1: J10.2, RN1.2 (R1), U4.4 (I0)
/KP_Col2: J10.3, RN1.3 (R2), U4.3 (I1)
/KP_Col3: J10.4, RN1.4 (R3), U4.2 (I2)
/KP_Col4: J10.5, RN1.5 (R4), U4.1 (I3)
/KP_Line1: J4.3, J7.3, J10.6, U1.4 (PD2)
/KP_Line2: J5.3, J8.3, J11.2, U1.3 (PD1)
/KP_Line3: J6.3, J9.3, J11.3, U1.2 (PD0)
/LED1: J4.4, U3.18 (O1)
/LED2: J7.4, U3.17 (O2)
/LED3: J5.4, U3.16 (O3)
/LED4: J8.4, U3.15 (O4)
/LED5: J6.4, U3.14 (O5)
/LED6: J9.4, U3.13 (O6)
/LED_Ctrl: J11.6, U3.12 (O7)
/MISO: J1.9, U1.18 (PB4), U3.4 (I4)
/MOSI: J1.1, U1.17 (PB3), U3.3 (I3)
/Reset: J1.5, U1.1 (~RESET/PC6)
/S0: U1.5 (PD3), U4.11 (S0)
/S1: U1.6 (PD4), U4.10 (S1)
/S2: U1.11 (PD5), U4.9 (S2)
/SCK: J1.7, U1.19 (PB5), U3.5 (I5)
/SCL: J2.7, U1.28 (PC5)
/SDA: J2.9, U1.27 (PC4)
/Volume: J3.2, U1.23 (PC0)
GND: C1.2, C2.2, C3.2, C4.2, C5.2, J1.4, J1.6, J1.8, J1.10, J2.8, J2.10, J3.3, J11.9, J11.10, U1.8 (GND), U1.22 (GND), U2.2 (GND), U3.8 (I8), U3.9 (GND), U4.7 (~E), U4.8 (GND)
unnamed: U1.14 (PB0), U3.7 (I7)
unnamed: U1.15 (PB1), U3.1 (I1)
unnamed: U1.16 (PB2), U3.2 (I2)
unnamed: U1.9 (XTAL1/PB6), U3.6 (I6)

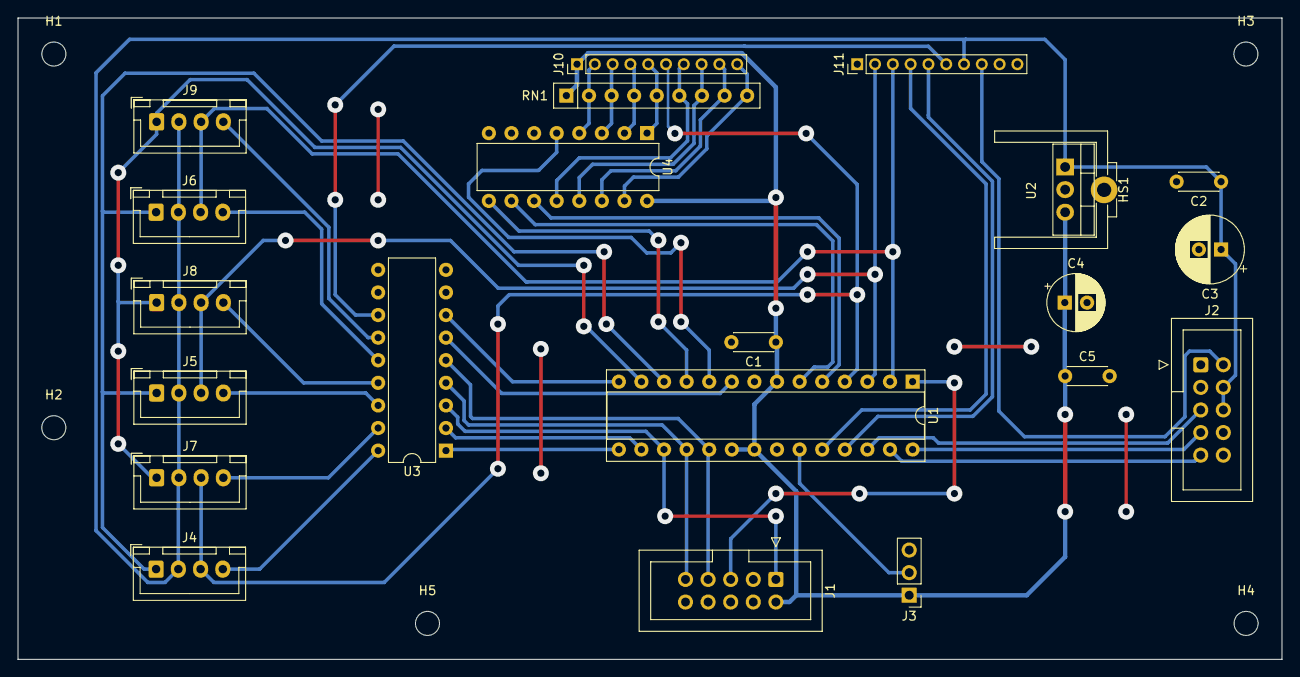
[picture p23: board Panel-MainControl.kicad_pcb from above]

Board: 2 copper layers, 142.1 x 72.1 mm, 27 parts (0 on the bottom side), 42 nets.

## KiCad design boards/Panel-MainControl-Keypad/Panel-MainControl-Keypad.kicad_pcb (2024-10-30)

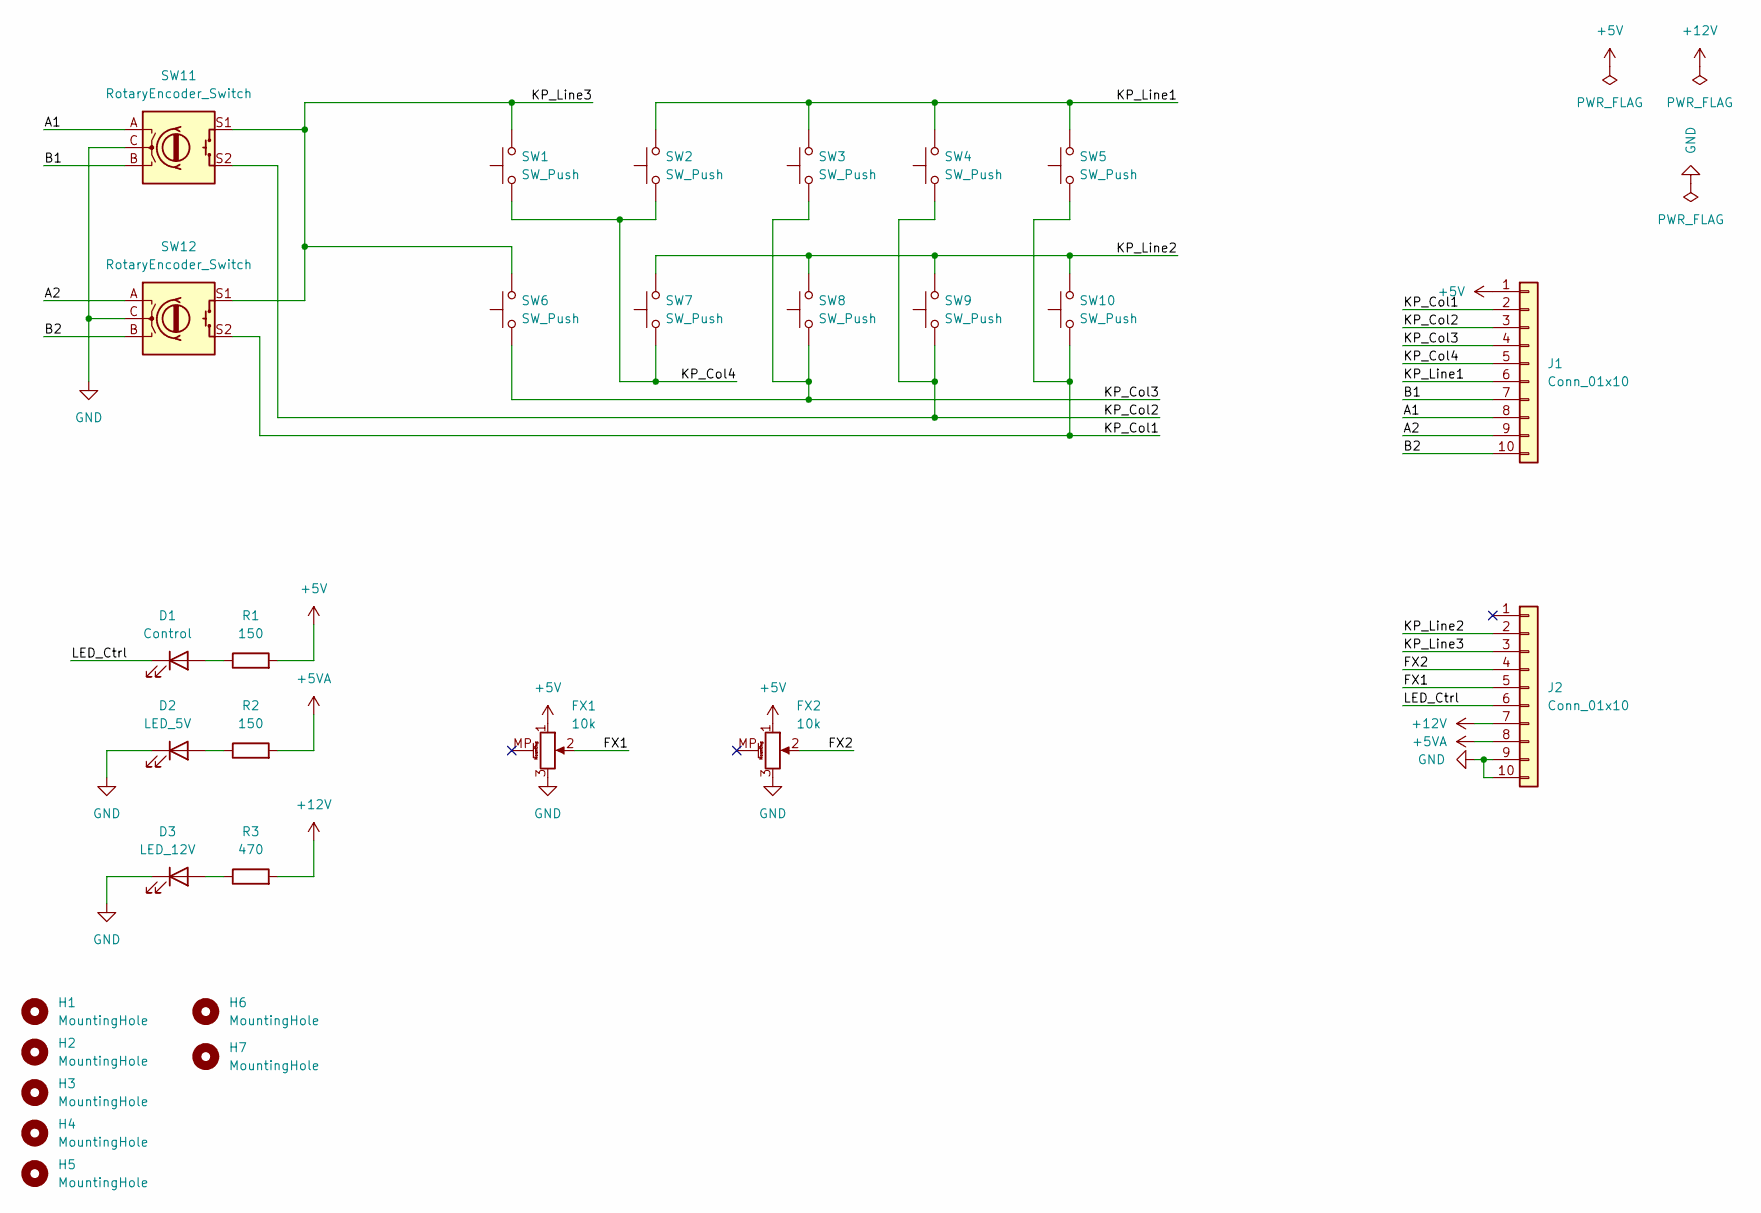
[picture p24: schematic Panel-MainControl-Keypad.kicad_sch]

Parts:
D1: Control; LED_Rectangular_W5.0mm_H2.0mm
D2: LED_5V; LED_Rectangular_W5.0mm_H2.0mm
D3: LED_12V; LED_Rectangular_W5.0mm_H2.0mm
FX1, FX2: 10k; Potentiometer_Alps_RK09K_Single_Vertical
H1, H2, H3, H4, H5, H6, H7: MountingHole; MountingHole_2.7mm_M2.5
J1, J2: Conn_01x10; PinHeader_1x10_P2.00mm_Vertical
R1, R2: 150; R_Axial_DIN0207_L6.3mm_D2.5mm_P10.16mm_Horizontal
R3: 470; R_Axial_DIN0207_L6.3mm_D2.5mm_P10.16mm_Horizontal
SW1, SW2, SW3, SW4, SW5, SW6, SW7, SW8, SW9, SW10: SW_Push; SW_PUSH_6mm_H9.5mm
SW11, SW12: RotaryEncoder_Switch; RotaryEncoder_Switch-PEC11R-4215F

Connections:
+5V: FX1.1, FX2.1, J1.1, R1.2
+5VA: J2.8, R2.2
+12V: J2.7, R3.2
/A1: J1.8, SW11.A
/A2: J1.9, SW12.A
/B1: J1.7, SW11.B
/B2: J1.10, SW12.B
/FX1: FX1.2, J2.5
/FX2: FX2.2, J2.4
/KP_Col1: J1.2, SW5.1, SW10.1, SW12.S2
/KP_Col2: J1.3, SW4.1, SW9.1, SW11.S2
/KP_Col3: J1.4, SW3.1, SW6.1, SW8.1
/KP_Col4: J1.5, SW1.1, SW2.1, SW7.1
/KP_Line1: J1.6, SW2.2, SW3.2, SW4.2, SW5.2
/KP_Line2: J2.2, SW7.2, SW8.2, SW9.2, SW10.2
/KP_Line3: J2.3, SW1.2, SW6.2, SW11.S1, SW12.S1
/LED_Ctrl: D1.1 (K), J2.6
GND: D2.1 (K), D3.1 (K), FX1.3, FX2.3, J2.9, J2.10, SW11.C, SW12.C
unnamed: D1.2 (A), R1.1
unnamed: D2.2 (A), R2.1
unnamed: D3.2 (A), R3.1

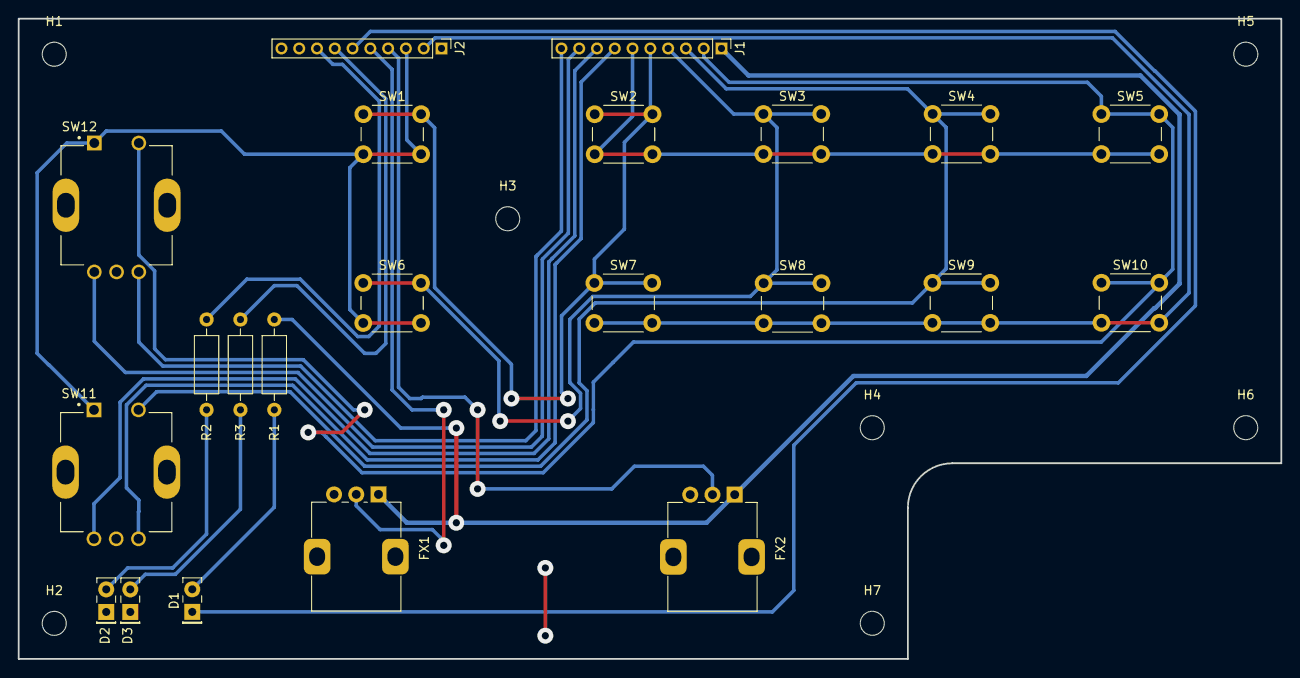
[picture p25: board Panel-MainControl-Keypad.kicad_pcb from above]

Board: 2 copper layers, 142.0 x 72.0 mm, 29 parts (0 on the bottom side), 21 nets.

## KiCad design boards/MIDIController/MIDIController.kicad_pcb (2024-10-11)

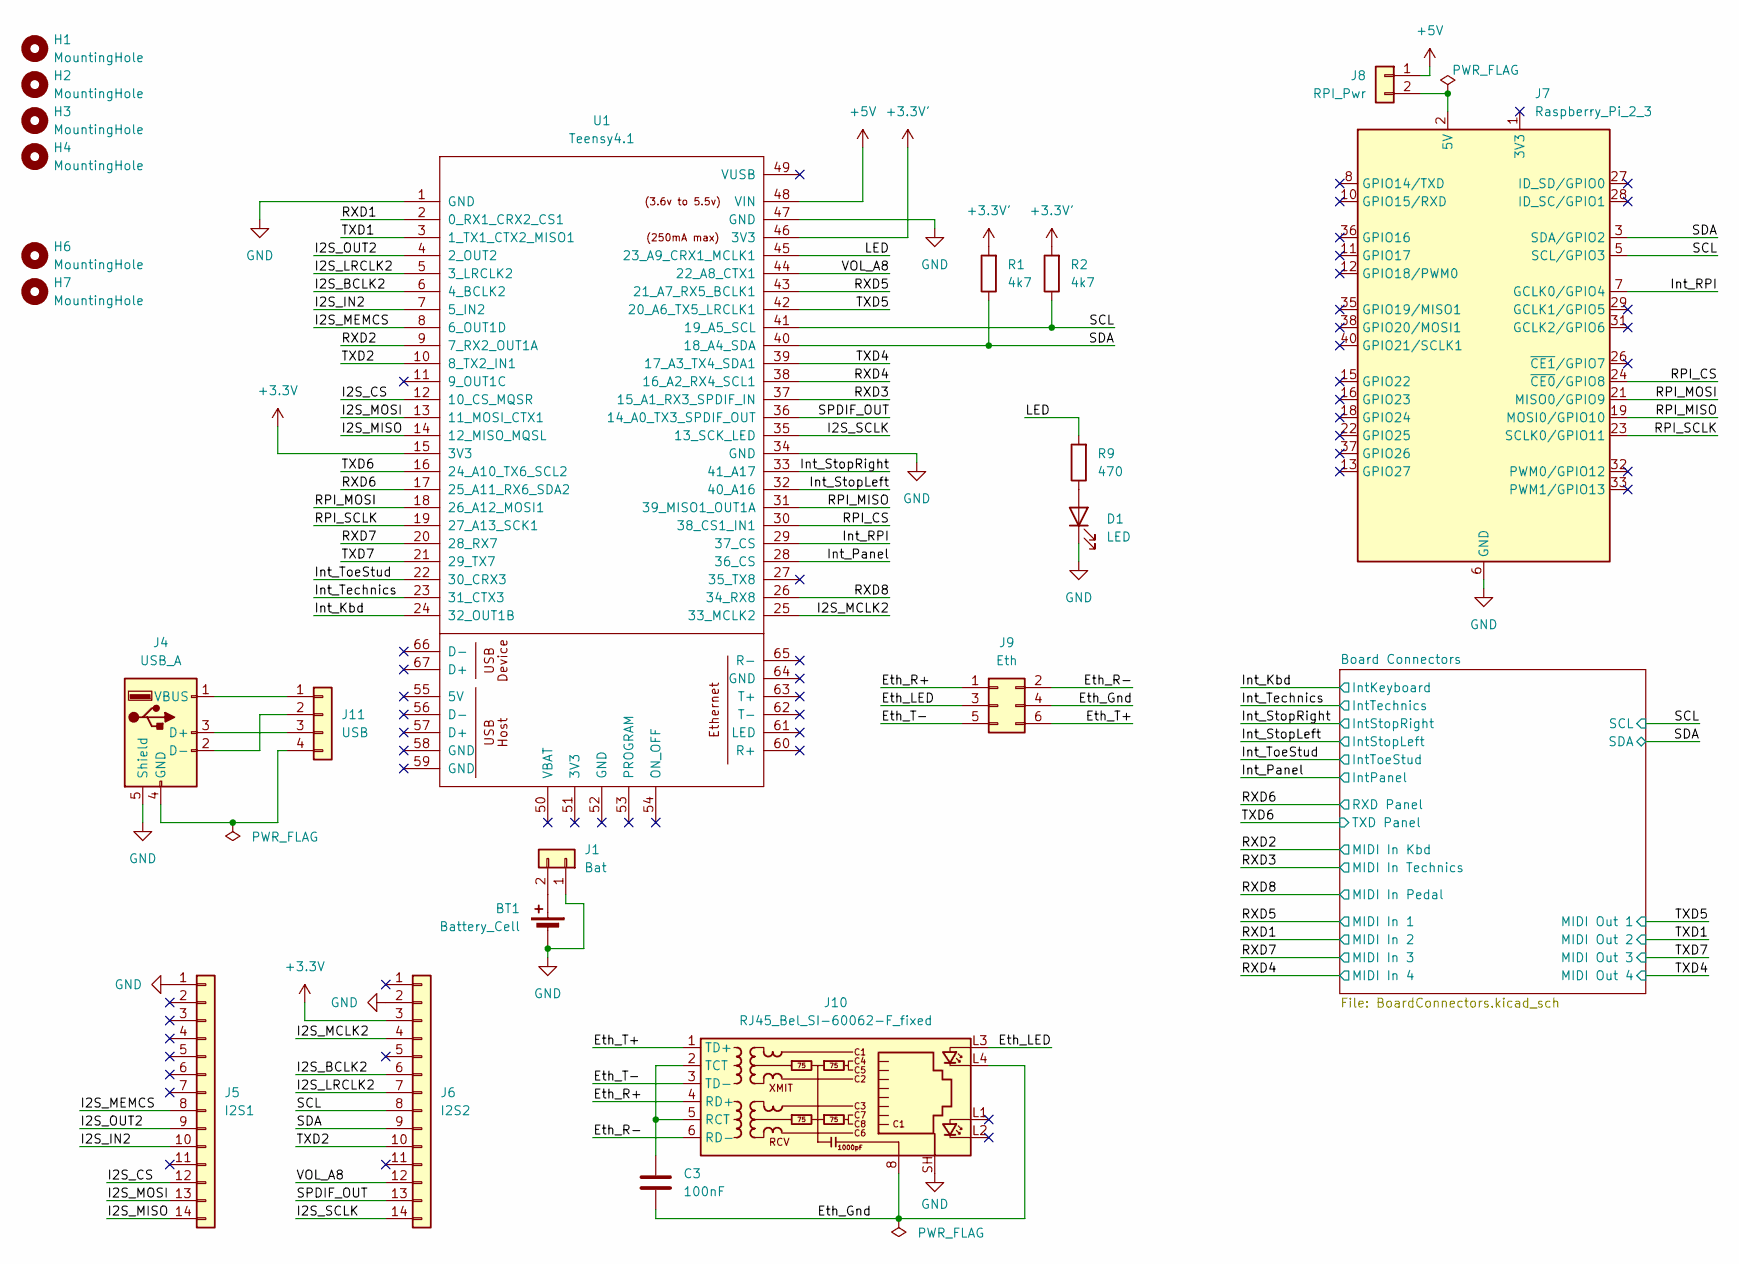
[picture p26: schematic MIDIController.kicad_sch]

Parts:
BT1: Battery_Cell; BatteryHolder_Holder_CR2032
C3: 100nF; C_Disc_D4.3mm_W1.9mm_P5.00mm
D1: LED; LED_D3.0mm
H1, H2, H3, H4: MountingHole; MountingHole_3.2mm_M3
H6, H7: MountingHole; MountingHole_2.7mm_M2.5
J1: Bat; PinHeader_1x02_P2.54mm_Vertical
J4: USB_A; USB_A_Molex_67643_Horizontal
J5: I2S1; PinHeader_1x14_P2.54mm_Vertical
J6: I2S2; PinHeader_1x14_P2.54mm_Vertical
J7: Raspberry_Pi_2_3; PinHeader_2x20_P2.54mm_Vertical
J8: RPI_Pwr; PinHeader_1x02_P2.54mm_Vertical
J9: Eth; PinHeader_2x03_P2.00mm_Vertical
J10: RJ45_Bel_SI-60062-F_fixed; RJ45_Bel_SI-60062-F
J11: USB; PinHeader_1x04_P2.54mm_Vertical
R1, R2: 4k7; R_Axial_DIN0207_L6.3mm_D2.5mm_P10.16mm_Horizontal
R9: 470; R_Axial_DIN0207_L6.3mm_D2.5mm_P10.16mm_Horizontal
U1: Teensy4.1; Teensy41

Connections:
+3.3V: J6.3, U1.15 (3V3); also elsewhere on the board
+3.3V': R1.2, R2.2, U1.46 (3V3)
+5V: J8.1, U1.48 (VIN); also elsewhere on the board
/Eth_Gnd: C3.2, J9.4, J10.8, J10.L4
/Eth_LED: J9.3, J10.L3
/Eth_R+: J9.1, J10.4 (RD+)
/Eth_R-: J9.2, J10.6 (RD-)
/Eth_T+: J9.6, J10.1 (TD+)
/Eth_T-: J9.5, J10.3 (TD-)
/I2S_BCLK2: J6.6, U1.6 (4_BCLK2)
/I2S_CS: J5.12, U1.12 (10_CS_MQSR)
/I2S_IN2: J5.10, U1.7 (5_IN2)
/I2S_LRCLK2: J6.7, U1.5 (3_LRCLK2)
/I2S_MCLK2: J6.4, U1.25 (33_MCLK2)
/I2S_MEMCS: J5.8, U1.8 (6_OUT1D)
/I2S_MISO: J5.14, U1.14 (12_MISO_MQSL)
/I2S_MOSI: J5.13, U1.13 (11_MOSI_CTX1)
/I2S_OUT2: J5.9, U1.4 (2_OUT2)
/I2S_SCLK: J6.14, U1.35 (13_SCK_LED)
/Int_Kbd: U1.24 (32_OUT1B); also elsewhere on the board
/Int_Panel: U1.28 (36_CS); also elsewhere on the board
/Int_RPI: J7.7 (GCLK0/GPIO4), U1.29 (37_CS)
/Int_StopLeft: U1.32 (40_A16); also elsewhere on the board
/Int_StopRight: U1.33 (41_A17); also elsewhere on the board
/Int_Technics: U1.23 (31_CTX3); also elsewhere on the board
/Int_ToeStud: U1.22 (30_CRX3); also elsewhere on the board
/LED: R9.2, U1.45 (23_A9_CRX1_MCLK1)
/RPI_CS: J7.24 (~CE0/GPIO8), U1.30 (38_CS1_IN1)
/RPI_MISO: J7.19 (MOSI0/GPIO10), U1.31 (39_MISO1_OUT1A)
/RPI_MOSI: J7.21 (MISO0/GPIO9), U1.18 (26_A12_MOSI1)
/RPI_SCLK: J7.23 (SCLK0/GPIO11), U1.19 (27_A13_SCK1)
/RXD1: U1.2 (0_RX1_CRX2_CS1); also elsewhere on the board
/RXD2: U1.9 (7_RX2_OUT1A); also elsewhere on the board
/RXD3: U1.37 (15_A1_RX3_SPDIF_IN); also elsewhere on the board
/RXD4: U1.38 (16_A2_RX4_SCL1); also elsewhere on the board
/RXD5: U1.43 (21_A7_RX5_BCLK1); also elsewhere on the board
/RXD6: U1.17 (25_A11_RX6_SDA2); also elsewhere on the board
/RXD7: U1.20 (28_RX7); also elsewhere on the board
/RXD8: U1.26 (34_RX8); also elsewhere on the board
/SCL: J6.8, J7.5 (SCL/GPIO3), R2.1, U1.41 (19_A5_SCL); also elsewhere on the board
/SDA: J6.9, J7.3 (SDA/GPIO2), R1.1, U1.40 (18_A4_SDA); also elsewhere on the board
/SPDIF_OUT: J6.13, U1.36 (14_A0_TX3_SPDIF_OUT)
/TXD1: U1.3 (1_TX1_CTX2_MISO1); also elsewhere on the board
/TXD2: J6.10, U1.10 (8_TX2_IN1)
/TXD4: U1.39 (17_A3_TX4_SDA1); also elsewhere on the board
/TXD5: U1.42 (20_A6_TX5_LRCLK1); also elsewhere on the board
/TXD6: U1.16 (24_A10_TX6_SCL2); also elsewhere on the board
/TXD7: U1.21 (29_TX7); also elsewhere on the board
/VOL_A8: J6.12, U1.44 (22_A8_CTX1)
GND: BT1.2 (-), D1.1 (K), J1.1, J4.5 (Shield), J5.1, J6.2, J7.6 (GND), J7.9 (GND), J7.14 (GND), J7.20 (GND), J7.25 (GND), J7.30 (GND), J7.34 (GND), J7.39 (GND), J10.SH, U1.1 (GND), U1.34 (GND), U1.47 (GND); also elsewhere on the board
unnamed: BT1.1 (+), J1.2
unnamed: D1.2 (A), R9.1
unnamed: J7.2 (5V), J7.4 (5V), J8.2
unnamed: C3.1, J10.2 (TCT), J10.5 (RCT)
unnamed: J4.1 (VBUS), J11.1
unnamed: J4.2 (D-), J11.2
unnamed: J4.3 (D+), J11.3
unnamed: J4.4 (GND), J11.4

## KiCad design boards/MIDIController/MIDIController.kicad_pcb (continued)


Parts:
C1: 100nF; C_Disc_D4.3mm_W1.9mm_P5.00mm
C2: 10uF; CP_Radial_D5.0mm_P2.00mm
C4, C5, C6, C7, C8, C9: 10nF; C_Disc_D3.8mm_W2.6mm_P2.50mm
J2: MIDICon; IDC-Header_2x08_P2.54mm_Vertical
J3: IO_Boards; IDC-Header_2x10_P2.54mm_Vertical
J12: LineIn; Jack_3.5mm_Ledino_KB3SPRS_Horizontal_Stereo
J13: LineOut; Jack_3.5mm_Ledino_KB3SPRS_Horizontal_Stereo
J14: Conn_02x05_Odd_Even; PinHeader_2x05_P2.54mm_Vertical
R3, R4, R5, R6, R7, R8: 100; R_Axial_DIN0207_L6.3mm_D2.5mm_P10.16mm_Horizontal

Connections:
+3.3V: J2.13, J2.15, J3.2; also elsewhere on the board
+5V: C1.1, C2.1, J2.14, J2.16, J3.18, J3.20; also elsewhere on the board
+12V: J3.8, J3.10
/Int_Kbd: C4.1, R3.1; also elsewhere on the board
/Int_Panel: C9.1, R8.1; also elsewhere on the board
/Int_StopLeft: C8.1, R7.1; also elsewhere on the board
/Int_StopRight: C7.1, R6.1; also elsewhere on the board
/Int_Technics: C5.1, R4.1; also elsewhere on the board
/Int_ToeStud: C6.1, R5.1; also elsewhere on the board
/RXD1: J2.9; also elsewhere on the board
/RXD2: J3.19; also elsewhere on the board
/RXD3: J3.17; also elsewhere on the board
/RXD4: J2.10; also elsewhere on the board
/RXD5: J2.12; also elsewhere on the board
/RXD6: J3.13; also elsewhere on the board
/RXD7: J2.8; also elsewhere on the board
/RXD8: J2.11; also elsewhere on the board
/SCL: J3.6; also elsewhere on the board
/SDA: J3.4; also elsewhere on the board
/TXD1: J2.5; also elsewhere on the board
/TXD4: J2.1; also elsewhere on the board
/TXD5: J2.7; also elsewhere on the board
/TXD6: J3.15; also elsewhere on the board
/TXD7: J2.3; also elsewhere on the board
GND: C1.2, C2.2, C4.2, C5.2, C6.2, C7.2, C8.2, C9.2, J2.2, J2.4, J2.6, J3.12, J3.14, J3.16; also elsewhere on the board
unnamed: J3.1, R8.2
unnamed: J3.3, R7.2
unnamed: J3.5, R6.2
unnamed: J3.7, R5.2
unnamed: J3.9, R4.2
unnamed: J3.11, R3.2
unnamed: J12.T, J14.1
unnamed: J12.G, J13.G, J14.2, J14.4, J14.7
unnamed: J12.S, J14.3
unnamed: J13.S, J14.5
unnamed: J13.T, J14.9


Board: 2 copper layers, 150.0 x 100.0 mm, 41 parts (0 on the bottom side), 70 nets.

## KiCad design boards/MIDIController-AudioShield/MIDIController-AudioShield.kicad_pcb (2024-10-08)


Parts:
H1, H2, H3: MountingHole; MountingHole_3.2mm_M3
J1: Conn_02x05_Odd_Even; PinHeader_2x05_P2.54mm_Vertical
J2: LineIn; Jack_3.5mm_Ledino_KB3SPRS_Horizontal_Stereo
J3: LineOut; Jack_3.5mm_Ledino_KB3SPRS_Horizontal_Stereo

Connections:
GND: J1.3, J1.8, J1.10, J2.G, J3.G
unnamed: J1.1, J3.T
unnamed: J1.5, J3.S
unnamed: J1.7, J2.S
unnamed: J1.9, J2.T


Board: 2 copper layers, 35.5 x 36.8 mm, 6 parts (0 on the bottom side), 5 nets.

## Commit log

2013-10-13 Initial commit or encoder boards
    [MatrixEncoder.sch, SwellEncoder.sch, ThumbEncoder.sch]
2013-10-14 Added schematics of thumb pistons
    [ThumbButtons.sch]
2013-10-14 Fixed thumb piston wiring schematics
    [ThumbButtons.sch]
2013-10-14 First version of thumb encoder schematics
    [SwellEncoder.sch, ThumbButtons.sch, ThumbEncoder.sch]
2013-10-15 Added first matrix encoder schematics, some design files
    [MatrixEncoder.sch, Organ.blend]
2013-10-15 Updated matrix encoder schematics
    [MatrixEncoder.sch]
2022-09-15 Added old firmware and design files
    [MatrixShiftEncoder.sch, MidiEncoder.sch, Organ.blend]
2022-10-30 Initial design files for new Console design.
    Moved old design to archive folder, updated some documents for new
    design.
    [Organ-v2.blend]
2022-11-13 New SwellEncoder schematics, updated MIDI paths in Boards diagram
    [SwellButtons.kicad_pcb, SwellButtons.kicad_sch, SwellEncoder.kicad_pcb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]
2022-11-19 Added Freecad files for toestop switch holder and button boxes
    [Interface Case.FCStd, Organ-v2.blend, Powerswitch Case.FCStd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]
2022-12-17 Updated 3D printed part designs and added STL exports
    [Doorknob.FCStd, Doorknob.stl, Hatchlock.FCStd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]
2022-12-17 Added Boutique retention hook design from https://www.thingiverse.com/thing:2430610
    [BoutiqueBracketWRetentionHook.stl]
2022-12-17 Fixed Boutique retention hook design to fit Roland SE-02
    [BoutiqueBracketWRetentionHook.stl]
2022-12-17 Renamed toestud encoder schematics
    [ToeStudButtons.kicad_pcb, ToeStudButtons.kicad_sch, ToeStudEncoder.kicad_pcb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]
2022-12-17 Renamed toe stud connectors
    [ToeStudButtons.kicad_sch]
2022-12-17 Renamed encoder boards and recreated with KiCAD 6
    [ChoirPisons.kicad_sch, KeyboardEncoder.kicad_pcb, KeyboardEncoder.kicad_sch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]
2022-12-18 Added schematics of pedal board controller
    [PedalEncoder.kicad_sch]
2022-12-18 Some updates to piston encoder schematics
    [PistonEncoder.kicad_sch]
2022-12-20 Updated Pedal Encoder to use UART from ToeStudEncoder
    [PedalEncoder.kicad_sch, PedalWires.kicad_pcb, PedalWires.kicad_sch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]
2022-12-20 Added Keyboard encoder and Midi encoder design using shift registers
    [KeyboardEncoder.kicad_sch, KeyboardShiftEncoder.kicad_pcb, KeyboardShiftEncoder.kicad_sch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]
2022-12-20 Finished Piston encoder schematics
    [PistonEncoder.kicad_sch]
2022-12-21 Updated keyboard encoder to use 8-1 Mux instead of shift registers
    [KeyboardEncoder.kicad_sch, MidiEncoder.kicad_sch, PowerPins.kicad_sch]
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2022-12-21 Added base schematics for Technics keyboard encoder
    [TechnicsEncoder.kicad_pcb, TechnicsEncoder.kicad_sch]
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2022-12-21 Added initial schematics for main controller board
    [BoardConnectors.kicad_sch, MIDI.kicad_sch, MainController.kicad_pcb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]
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2023-04-19 Renamed PCBs and updated to KiCAD 7.0
    [BoardConnectors.kicad_sch, ChoirPisons.kicad_sch, KeyboardEncoder.kicad_sch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]
2023-04-19 Moved individual part designs into subfolder
    [BoutiqueBracketWRetentionHook.stl, Doorknob.FCStd, Doorknob.stl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]
2023-04-23 Created new signals drawings
    [MIDI.kicad_sch, MIDIController.kicad_sch]
2023-10-21 Added Audio/MIDI routes diagram
    [Music Rack.FCStd]
2023-10-21 PCB layout for keyboard scanner and piston encoder
    [KeyboardEncoder.kicad_pcb, KeyboardEncoder.kicad_sch, KeyboardScanner.kicad_pcb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]
2024-01-13 Added redesigned Roland Boutique holder
    [BoutiqueBracketWRetentionHook-LBracket.step, BoutiqueBracketWRetentionHook-RBracket.step, BoutiqueBracketWRetentionHook.FCStd]
2024-02-07 Added Audio frontpanel, added more MIDI ports to controller
    [Audio Frontpanel-Panel.step, Audio Frontpanel.FCStd, MIDIController.kicad_sch]
2024-02-13 Added output buffer to MIDI outputs
    [KeyboardEncoder.kicad_sch, TechnicsEncoder.kicad_sch, ToeStudEncoder.kicad_sch]
2024-03-04 Updated to KiCAD 8, fixed optocouplers for MIDI and added powersupplies
    [ChoirPisons.kicad_sch, KeyboardEncoder.kicad_pcb, KeyboardEncoder.kicad_sch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]
2024-03-04 New PCB version of PedalEncoder
    [PedalEncoder.kicad_pcb, PedalEncoder.kicad_sch]
2024-03-05 Using custom TO220 cooler, fixed and finished several PCBs
    [KeyboardEncoder.kicad_pcb, KeyboardEncoder.kicad_sch, PedalEncoder.kicad_pcb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]
2024-03-05 Finished PCB for ToeStudEncoder
    [ToeStudEncoder.kicad_pcb, ToeStudEncoder.kicad_sch]
2024-03-06 Cleanup of PCB sizes and mounthole positions. Moved MIDI connectors to separate board.
    [BoardConnectors.kicad_sch, KeyboardEncoder.kicad_pcb, KeyboardScanner.kicad_pcb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]
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2024-03-07 Added Optocoupler and RS232 converter to UART board lines.
    [BoardConnectors.kicad_sch, KeyboardEncoder.kicad_pcb, KeyboardEncoder.kicad_sch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]
2024-03-08 Finished IO-Board PCB, switched RX/TX of board connectors for better routing
    [KeyboardEncoder.kicad_pcb, KeyboardEncoder.kicad_sch, MIDIController-IO-Boards.kicad_pcb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]
2024-03-08 Finished connectors on MIDIController board, fixed 3.3V IO voltage levels
    [BoardConnectors.kicad_sch, MIDIController-IO-Boards.kicad_pcb, MIDIController-IO-Boards.kicad_sch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]
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2024-03-11 Fixed interrupt line to use open collector, added pullups to I2C lines
    [BoardConnectors.kicad_sch, Connectors.kicad_sch, KeyboardEncoder.kicad_pcb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]
2024-03-11 Added CR2032 holder footprint, allow routing between pins
    [BoardConnectors.kicad_sch, MIDIController.kicad_pcb, MIDIController.kicad_sch]
2024-03-13 Added bypass caps to power supplies, use cheaper MAX232 IC.
    [Connectors.kicad_sch, KeyboardEncoder.kicad_pcb, KeyboardEncoder.kicad_sch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]
2024-05-18 Updated design rules to 0.32mm template and exported Gerber files
    [BoardConnectors.kicad_sch, Connectors.kicad_sch, KeyboardEncoder.kicad_pcb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]
2024-06-16 Fixed some RX/TX pin swaps
    [BoardConnectors.kicad_sch, MIDIController-IO-Boards.kicad_pcb, MIDIController-IO-Boards.kicad_sch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]
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2024-06-26 Fixed size of I2C expander board footprint
    [MIDIController-IO-Boards.kicad_pcb, MIDIController-IO-Boards.kicad_sch, MIDIController.kicad_pcb]
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2024-06-30 Make Toestud PS2 connectors symmetrical to avoid connection errors
    [Connectors.kicad_sch, MIDIController-IO-Boards.kicad_pcb, ToeStudEncoder.kicad_pcb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]
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2024-06-30 ToeStudEncoder: Fixed mirrored PS2 pinout
    [ToeStudEncoder.kicad_pcb, ToeStudEncoder.kicad_sch]
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2024-07-03 Fixed mirrored MIDI board connector
    [BoardConnectors.kicad_sch, MIDIController.kicad_pcb, MIDIController.kicad_sch]
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2024-07-10 Fixed Piston wiring schematics, updated I2C message formats
    [ChoirPisons.kicad_sch, PistonWires.kicad_sch, SwellGreatPistons.kicad_sch]
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2024-08-03 Fixed PedalEncoder ISP hedaer schematics, added Errata notes
    [PedalEncoder.kicad_pcb, PedalEncoder.kicad_sch]
2024-08-05 Fixed PedalEncoder ISP connections
    [PedalEncoder.kicad_pcb, PedalEncoder.kicad_sch]
2024-08-30 Fixed KeyboardScanner schematics to fix open collector enable output
    [KeyboardScanner.kicad_sch, Multiplexers.kicad_sch]
2024-08-31 Revert "Fixed KeyboardScanner schematics to fix open collector enable output"
    This reverts commit 57decbb2314c6d76a4ad6cd92ca682e4977913ef.
    [KeyboardScanner.kicad_sch, Multiplexers.kicad_sch]
2024-08-31 Replaced inverting with non-inverting output buffer in KeyboardScanner to fix disabled open collector output
    [KeyboardScanner.kicad_pcb, KeyboardScanner.kicad_sch]
2024-08-31 Reverting to using 2803A inverted open collector for Keyboard Scanner, fixed layout
    [KeyboardScanner.kicad_pcb, KeyboardScanner.kicad_sch, Multiplexers.kicad_sch]
2024-09-02 Added IDC16 connector workaround, PCB holder for TechnicsEncoder
    [IDC16-ReverseConnector.kicad_pcb, IDC16-ReverseConnector.kicad_sch, PCB Holder Technics-Holder 110x53.step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]
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2024-09-07 Fixed LEDController button header layout
    [LEDController.kicad_pcb, LEDController.kicad_sch]
2024-09-13 Revert "Reverting to using 2803A inverted open collector for Keyboard Scanner, fixed layout"
    This reverts commit 7b46a6886eac97662925cbadd02de0ff96663bd2.
    [KeyboardScanner.kicad_pcb, KeyboardScanner.kicad_sch, Multiplexers.kicad_sch]
2024-09-13 Revert "Replaced inverting with non-inverting output buffer in KeyboardScanner to fix disabled open collector output"
    This reverts commit 6ddf25a0a7a31b9f16f3f110cd3b7ae66d122c97.
    [KeyboardScanner.kicad_pcb, KeyboardScanner.kicad_sch]
2024-09-13 Fixed pulldown resistors for KeyboardScanner
    [KeyboardScanner.kicad_pcb, KeyboardScanner.kicad_sch]
2024-10-08 Added keyboard locking mount model, initial Line audioshield board
    [Lock Mount-Body Left.step, Lock Mount-Body Right.step, Lock Mount.FCStd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]
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2024-10-08 Fixed swapped I2S data lines in schematics
    [BoardConnectors.kicad_sch, MIDIController.kicad_sch]
2024-10-08 Fixed MIDIController I2S PCB, added LED
    [BoardConnectors.kicad_sch, MIDIController.kicad_pcb, MIDIController.kicad_sch]
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2024-10-30 Added 3d parts for music stand, display holder
    [Display Clamp.FCStd, Display Clamp.step, Musicstand Holder-Spacer.step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]
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2024-10-30 Fixed using 5V from main power for PWR LED
    [Panel-MainControl-Keypad.kicad_pcb, Panel-MainControl-Keypad.kicad_sch, Panel-MainControl.kicad_pcb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]
2024-11-02 Fixes for missing pullups on keypad buttons
    [Panel-MainControl-Adapter.kicad_pcb, Panel-MainControl-Adapter.kicad_sch, Panel-MainControl.kicad_pcb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]
2024-11-02 Updated panel breakout board to use second I2C to avoid conflict with display
    [Panel-Breakout.kicad_pcb, Panel-Breakout.kicad_sch, Panel-MainControl-Adapter.kicad_pcb]
2024-11-02 Fixed missing I2C pullup for Raspberry I2C-0
    [Panel-Breakout-I2CPullup.kicad_pcb, Panel-Breakout-I2CPullup.kicad_sch, Panel-Breakout.kicad_pcb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]
2024-11-07 Disconnected UART lines to avoid interference
    [ToeStudEncoder.kicad_pcb, ToeStudEncoder.kicad_sch]
